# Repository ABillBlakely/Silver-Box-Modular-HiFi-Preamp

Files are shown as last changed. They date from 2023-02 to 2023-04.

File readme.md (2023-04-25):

# Silver Box Modular HiFi Preamp

> __Note: This project is still very early in development. Features, functions, and interfaces are subject to change.__

The Silver Box Modular HiFi Preamp allows a person to choose the exact inputs and outputs that a user wants to have. It is common to need to combine or switch between many different sources which all need to go to a single playback source. For instance a person may have TOSLINK optical from their TV, RCA source from a turntable, and a balanced source from a USB audio interface. With this device, all of those can be accommodated and output to one set of speakers.

The chassis provides the analog signal routing, volume control, switching and indication. It is driven by an ESP32 so that functions can be controlled over WiFi, and eventually with smart home integration.

Peripherals are modular cards that can be slotted in to any of the available channels. Peripherals can be active or passive and can function as inputs, outputs, effects, visualizations, maybe more!

The chassis provides each peripheral with:

- Audio send to summing bus, main bus audio output, and audio out from left-adjacent module.
- Global mute and per peripheral muting.
- +/- 12V, +5V, +3.3V power rails.
- An I2C data interface with interrupt capabilities.
- Automatic identification of common module types with additional configuration possible over I2C.

# Current Status

__April 25 2023 Update:__ The project is currently in the __hardware prototyping__ phase. PCB's have been produced and are being assembled. Very close to beginning testing. A minimum viable product could be functional by end of May 2023.

Design files will be updated here as progress is made.

The current schematics are available in .pdf in the __ecad__ folder:

- [ecad/motherboard.pdf](ecad/motherboard.pdf)
- [ecad/controlboard.pdf](ecad/controlboard.pdf)
- [ecad/peripheral-example-board.pdf](ecad/peripheral-example-board.pdf)
- [ecad/prototype-power-supply.pdf](ecad/prototype-power-supply.pdf)

The current 3D models/assemblies for the project are available in .step format in the __mcad__ folder:

- [mcad/silver-box-modular_assembly.step](mcad/silver-box-modular_assembly.step)
- [mcad/motherboard.step](mcad/motherboard.step)
- [mcad/controlboard.step](mcad/controlboard.step)
- [mcad/peripheral-example-board.step](mcad/peripheral-example-board.step)

The BOM for this project is evolving and changing with the project. The current state of the BOM can be viewed at 

- [Motherboard](https://octopart.com/bom-tool/XiIWqOJY)
- [Peripheral test board](https://octopart.com/bom-tool/2ID8Y56N)
- [Protype power supply](https://octopart.com/bom-tool/b4PDtAU9)

Next steps:

- [ ] Bring docs up to date with current development state.
- [ ] Setup dev environment
- [ ] Document the mcad model and explain key features.
- [ ] Organize and refine the 3d prints that will be required for the prototype.
- [ ] Put together power supply module that will be used for early development.
  	- Board should have breakouts for external lab power option
  	- MCU for development and testing of I2C, power sequencing, power monitoring
  	- Polyfuse or other protection circuit. 
- [x] Create blank/passive modules for prototyping.
- [x] Synchronize/clean the Octopart BOM with the schematic.
- [x] Final review and production of prototype PCB's.

Farther out:

- 4 layer board after hardware features and form is frozen.
- Power supply design following findings learned from prototyping efforts.
- Expand available peripheral designs, active balanced I/O. Headphone amp output, S/PDIF digital input, VU 
- Integrate with MQTT for smart home capabilities. Eventual integration with commercial smart home systems.

# Concept sketches/renders:

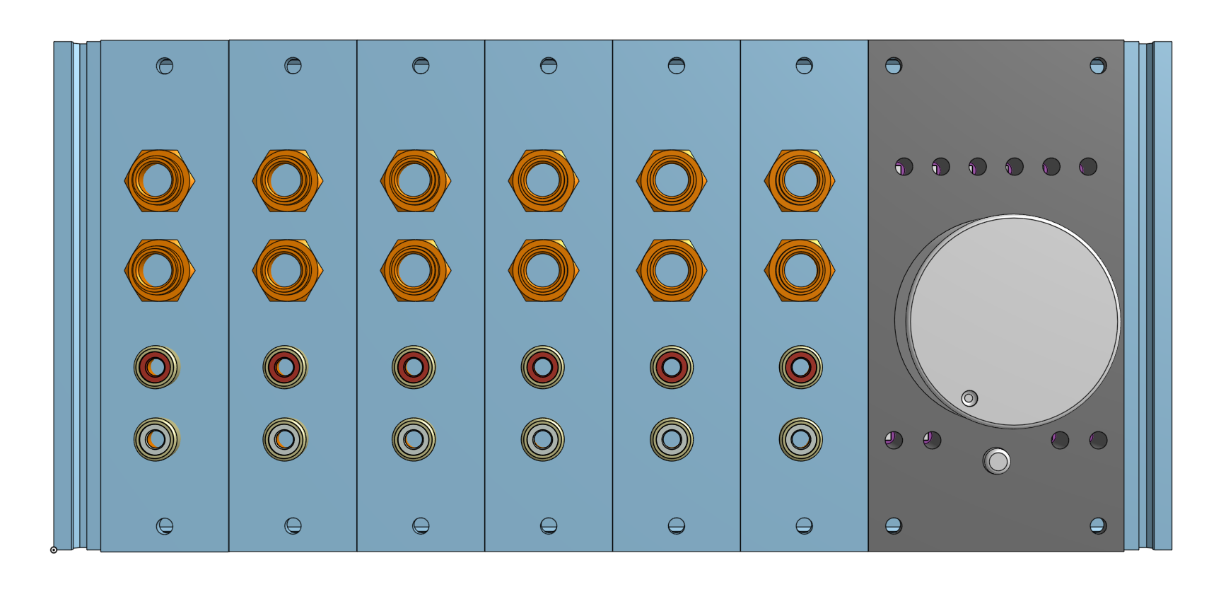
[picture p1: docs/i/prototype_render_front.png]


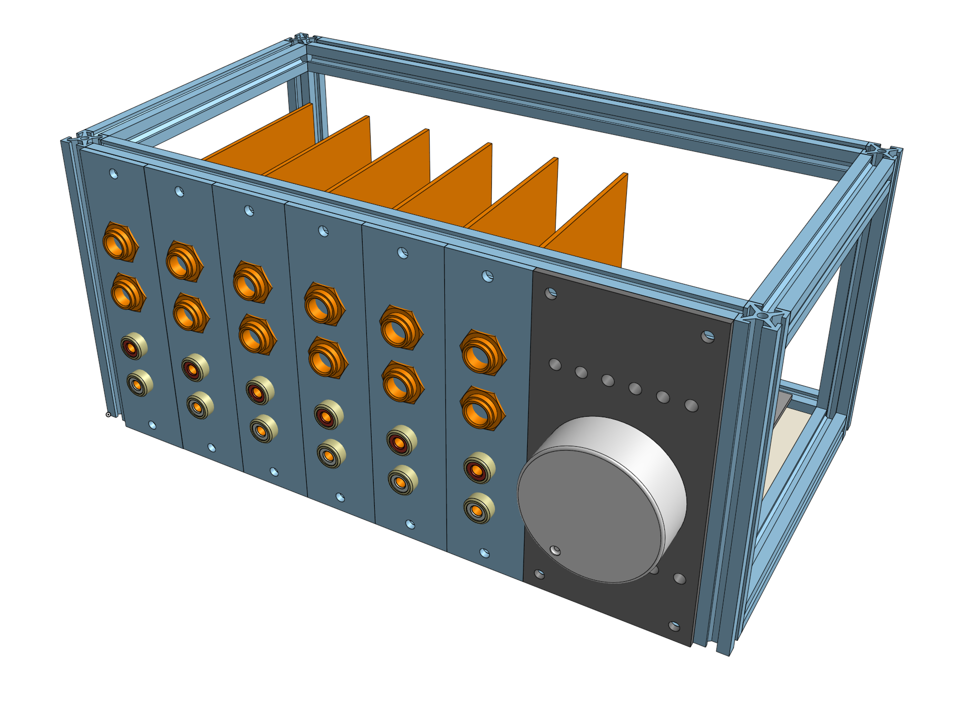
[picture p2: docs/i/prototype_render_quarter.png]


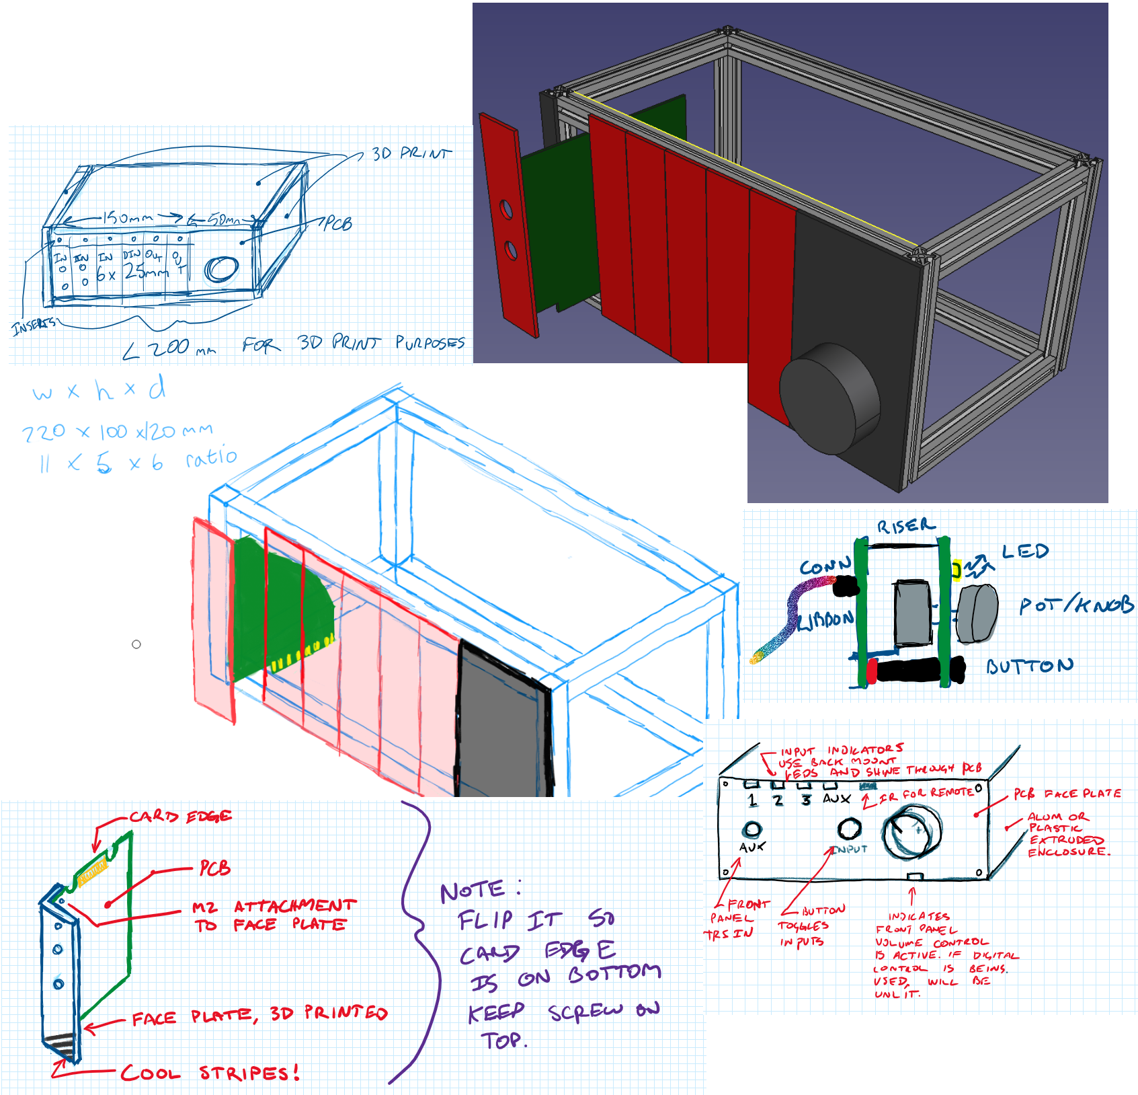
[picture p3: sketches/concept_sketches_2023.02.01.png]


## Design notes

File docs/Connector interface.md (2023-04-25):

# Connector Interface

The Silver Box Modular HiFi Preamp allows a user to swap cards, called peripherals, to facilitate a wide variety of desired input and output combinations. The controller provides the ability to mute individual inputs and provides volume control. The modular interface relies on a 36 pin PCI card edge connector. This connector supplies the peripheral with power, ID's the peripherals function, allows digital communications, and connects the stereo audio to three connection points, described below.

# Audio Send/Receive

Each module has one send and two receives available. Each of these endpoints is a stereo connection.

* __POMI__ Peripheral Out Master In: This sends audio that comes in from an external connector out to the master bus. The controller provides the facility to mute each individual stereo pair sent to POMI. All POMI sends are summed together and sent to the volume control.

* __MOPI__ Master Out, Peripheral In: The signal from the volume control is fed out to every module. Every module sees the same summed signal simultaneously. This means that multiple output peripherals can be installed, but the controller will not be able to select between them. If this behavior is req'd, an advanced output peripheral that includes muting/volume control plus I2C communication should be used.

* __AOPI__ Adjacent Out, Peripheral In: This signal ties to POMI signal of the left-hand adjacent module. It does not go through the buffer, muting, summing, or volume control; it is the raw unbuffered signal from that module. It can be used for a variety of cases such as Input VU meter, Input EQ/Trim, or as a way to bypass the controller board and feed an output module directly. 

# Power

There are 4 power rails available:

* +/-15 V supply is intended to be the analog power supply and should to be used to power any active audio components on the board. 
* 5 V and 3.3 V supplies are intended primarily to power digital devices, These can be used for audio purposes but are generally much noisier. The 5V rail should also be used to pull up the ID pins.

Each power rail has a separate ground return pin on the connector and care should be taken to maintain good routing of these return paths. 

# ID3:0

The ID pins are used to pass basic information about the peripheral back to the controller. This allows for automatic configuration and adaptation of the user interface when a peripheral is swapped. For example, the input button will not select peripherals that do not set the Is_input ID bit. More advanced peripherals can communicate over I2C for additional configuration, but should still communicate as much info as possible over the ID pins. 

> __Note 1: The ID Bit definition is a work in progress and subject to change.__

<!-- I'm not sure if I like "...not output or does not receive...". I might need to include output / not output as well, this could be done without multi state id's by merging USE I2C to the ~INT pin, See Note 2. This decision really comes down to: does the controller need to know what is and is not a simple output.-->

IDN: Low / High

ID0: Sends to POMI (is an input) / No Send (is not an input)

ID1: Receive from AOPI, is output (Ex: controller bypass)/ Receive from AOPI, is not output (ex: Input VU) OR does not receive from AOPI

ID2: Receives from MOPI (is output) / Receive from MOPI but not output (ex: out VU) OR does not receive from MOPI

ID3: Uses I2C / does not use I2C

For instance, the special case of all "high" values could be used in the case of an input VU meter. It receives the unbuffered audio from the adjacent peripheral and visualizes the levels of the input with an led bar graph.

In the future, ID pins may be multi state to allow configuration of more options so to maintain future compatibility ID pins should be strongly pulled up or down. 

# I2C

The controller allows for I2C communication to establish more advanced behavior. As the controller firmware matures, more advanced features will be added to the peripherals. 

The controller I2C bus is multiplexed so each peripheral has a dedicated I2C channel. This prevents any potential conflict in addresses between boards. 

When a peripheral is detected with the "Use I2C" ID pin set, the full address space is scanned to detect all available I2C endpoint addresses. peripherals must set an interrupt in order to send information back to the controller. 

Peripheral/controller communication will function based on a subscribe/notify style of communication. 

# Special Note: Peripheral insertion detection with ~INT and ID3

In the special case where a peripheral is configured with ID3:0 == 1111, it is not possible to determine whether a slot is empty or occupied. For this reason the controller relies on the ~INT pin being pulled low to indicate that a peripheral is inserted. The controller will then scan the ID bits, If  "Use I2C" Bit is also low, the controller will look for a message: a configuration message will indicate a new peripheral and any other message will indicate an unchanged peripheral. If the "Use I2C" bit is high, this will also indicate a new peripheral, and the controller will initialize the new peripheral. 

__In other words, peripherals not using I2C should pull ~INT low, and peripherals with I2C should send an interrupt on power up.__

> __Note 2: ID3 and ~INT could be combined, an ~INT that stays low would indicate no I2C use, and an ~INT the is triggered and then goes high would indicate I2C use. interrupts would need to be under 50ms or something.__

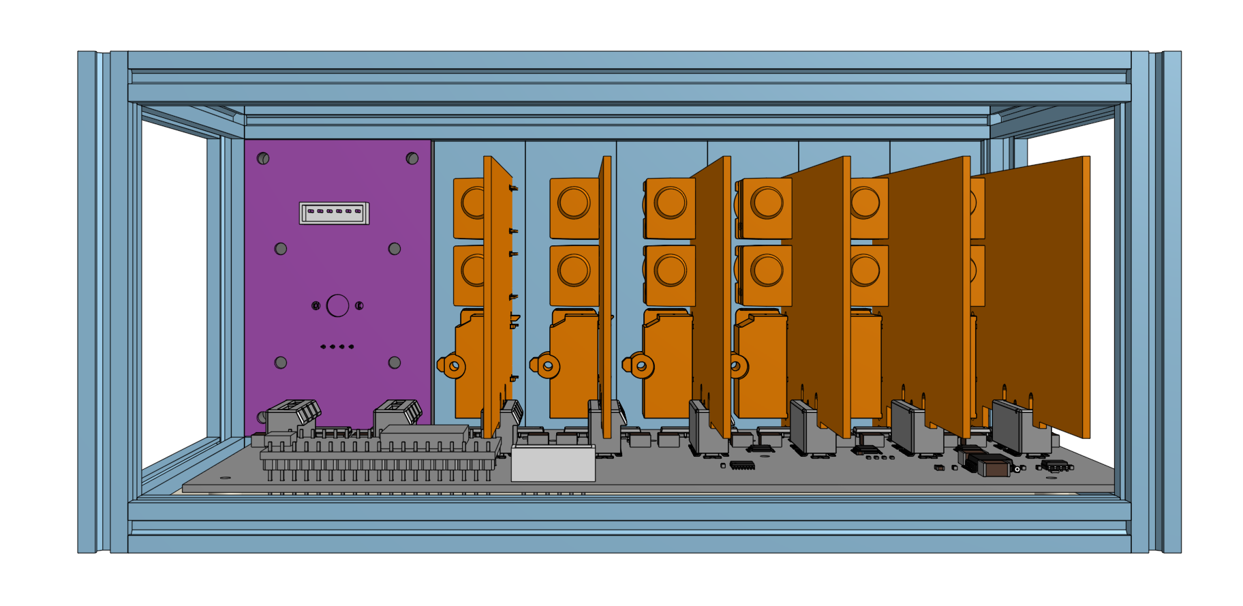
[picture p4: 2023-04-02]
docs/i/prototype_render_back.png

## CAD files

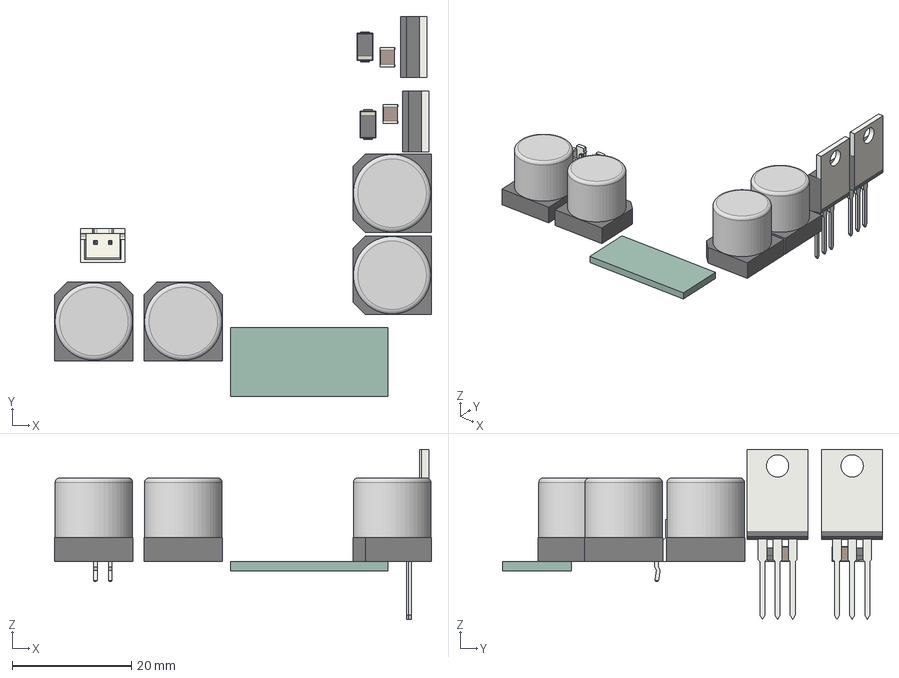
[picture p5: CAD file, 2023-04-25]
mcad/prototype-power-supply.step
63.2 x 63.8 x 28.5 mm
prototype-power-supply PCB

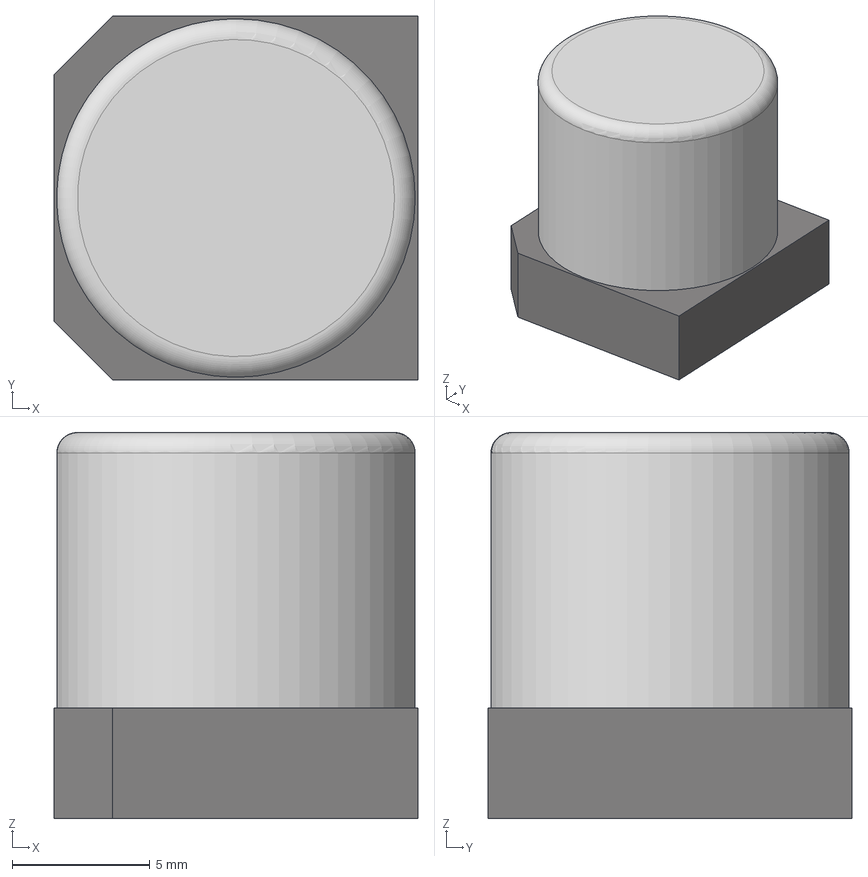
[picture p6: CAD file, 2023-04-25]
mcad/Cap_Elec_12.5x13.5.step
13.2 x 13.2 x 14.0 mm

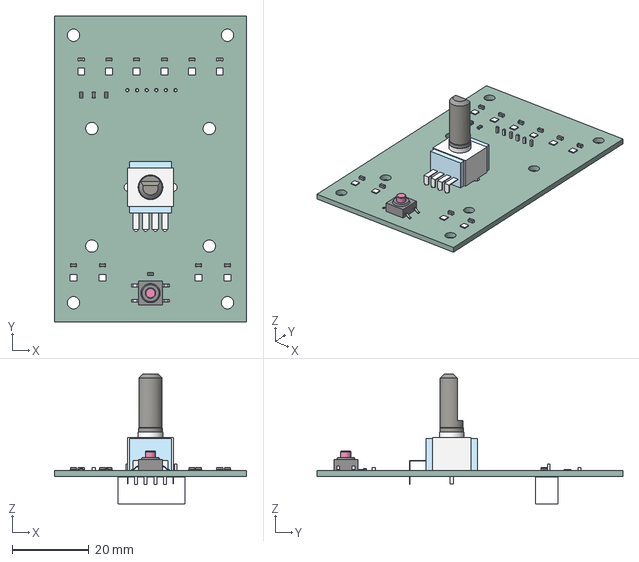
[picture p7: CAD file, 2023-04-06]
mcad/controlboard.step
50.0 x 79.5 x 33.7 mm
PCB

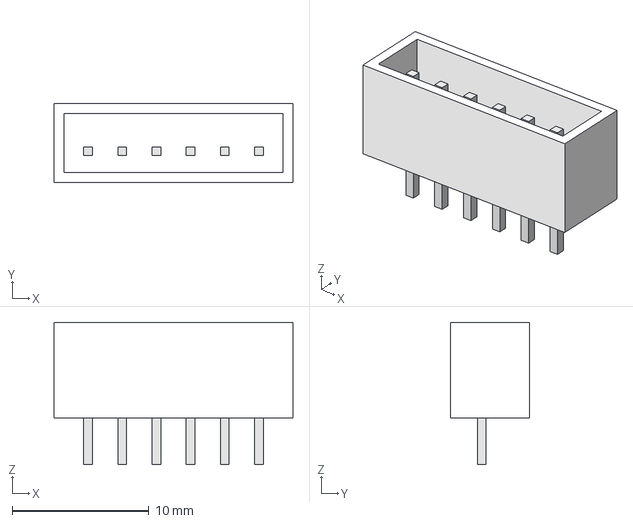
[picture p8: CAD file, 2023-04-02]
mcad/JST-XH-6A.step
17.5 x 5.80 x 10.4 mm

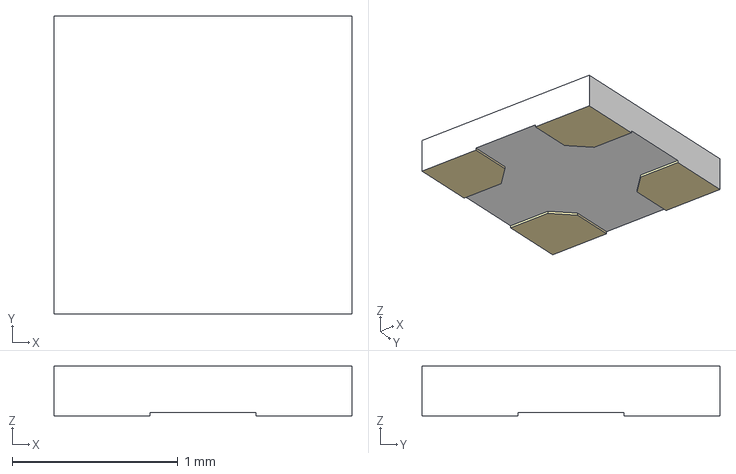
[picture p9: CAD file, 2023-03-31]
mcad/19-C47 RSGHBHC-5V01 2T.step
1.80 x 1.80 x 0.3 mm

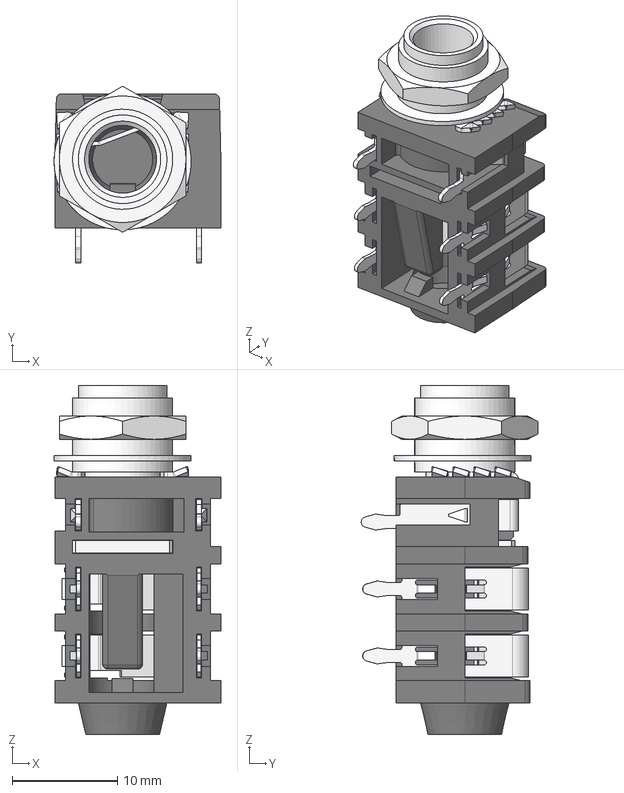
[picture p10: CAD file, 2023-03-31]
mcad/ACJS-MHOM.step
15.8 x 16.7 x 33.1 mm

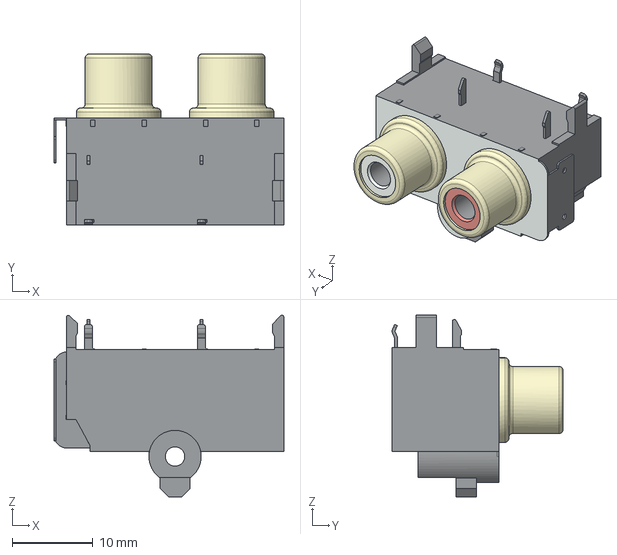
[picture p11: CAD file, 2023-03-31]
mcad/pjras2x1s_series.step
28.5 x 21.2 x 22.5 mm

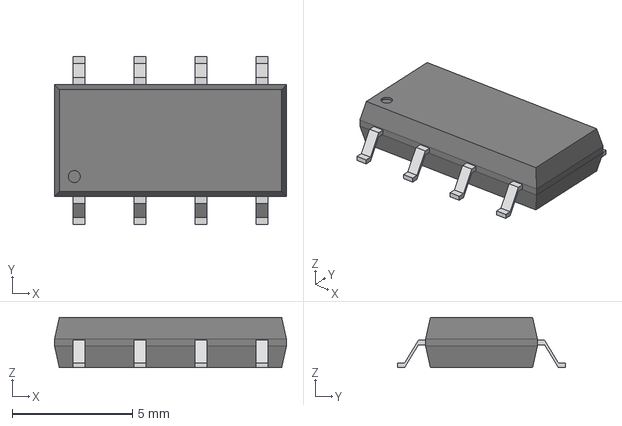
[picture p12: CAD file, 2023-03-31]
mcad/TLP4026G.step
9.65 x 7.00 x 2.10 mm

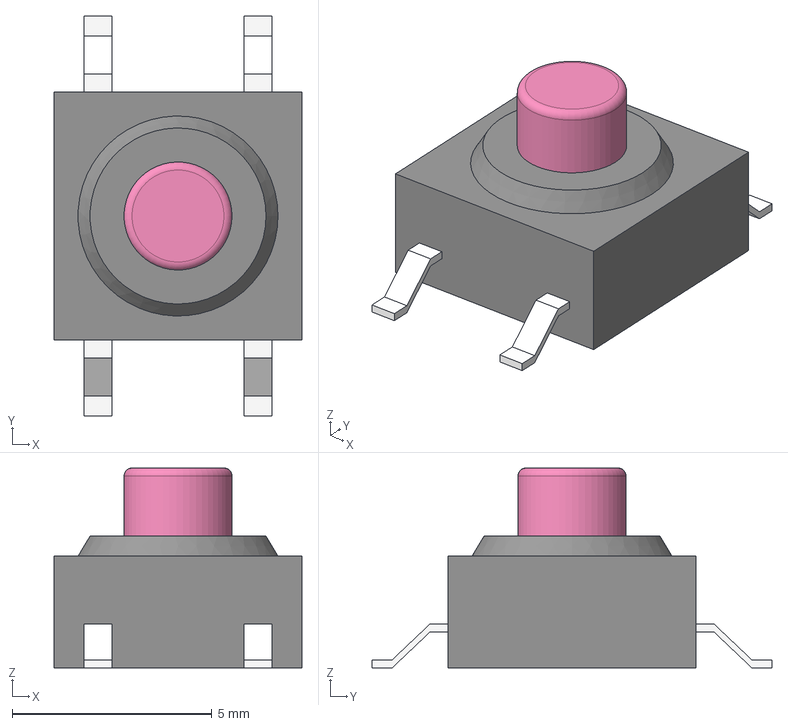
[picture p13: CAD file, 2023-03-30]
mcad/CK switches KSC SLT G.step
6.20 x 10.0 x 5.00 mm

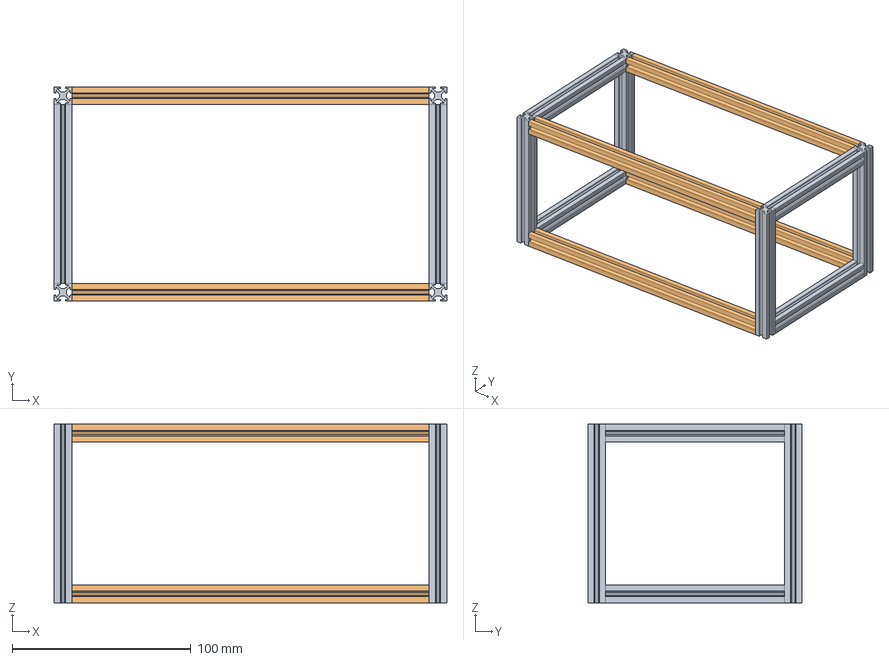
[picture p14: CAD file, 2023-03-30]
mcad/prototype frame.step
220.0 x 120.0 x 100.0 mm
Frame height 2
Frame height 3
Frame height 4
Frame width 1
Frame width 2
Frame width 3
Frame width 4
Frame depth 1
Frame depth 2
Frame depth 3
Frame depth 4
Frame height 1

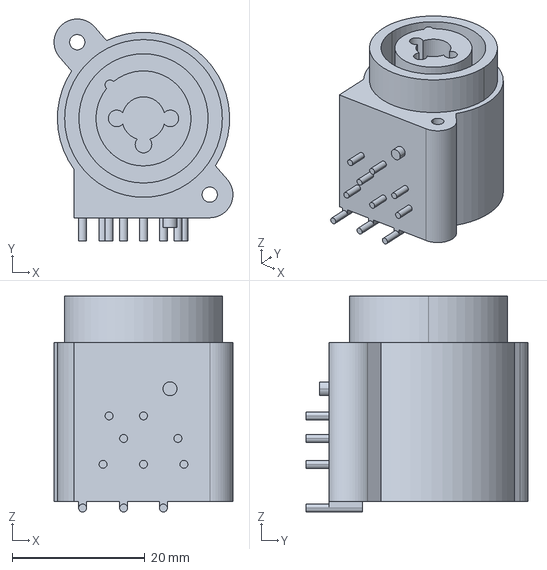
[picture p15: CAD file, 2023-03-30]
mcad/Neutrik ncj9fi-h-0.step
27.0 x 33.5 x 32.6 mm

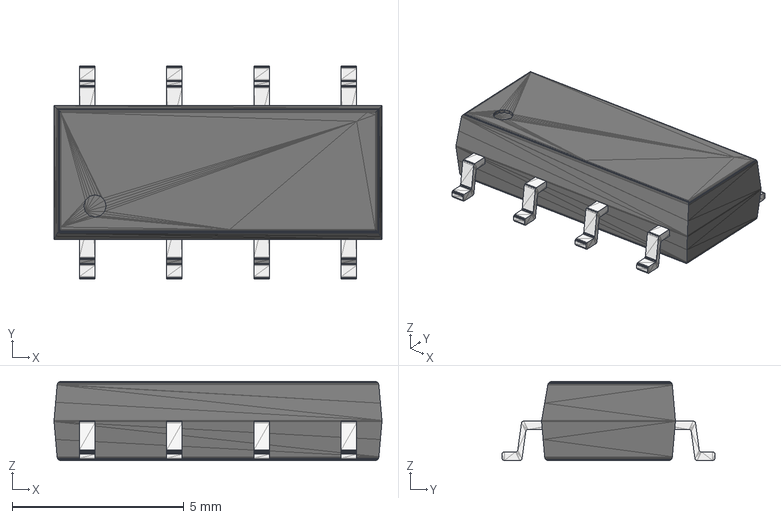
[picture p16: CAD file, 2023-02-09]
mcad/CPC2317N.step
9.55 x 6.20 x 2.30 mm
cpc2317M_body001
cpc2317M_pins001 (Solid)

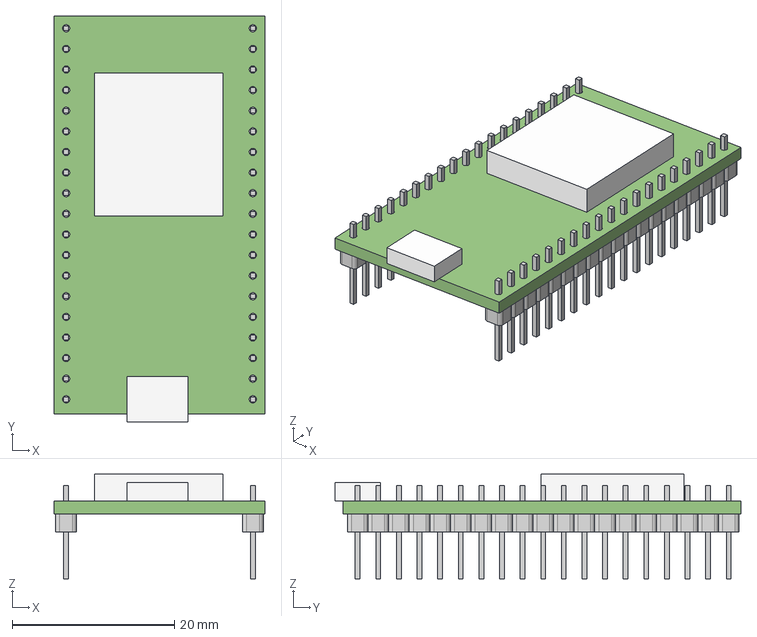
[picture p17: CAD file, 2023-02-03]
mcad/NodeMCU ESP-32S.step
26.0 x 50.0 x 12.9 mm

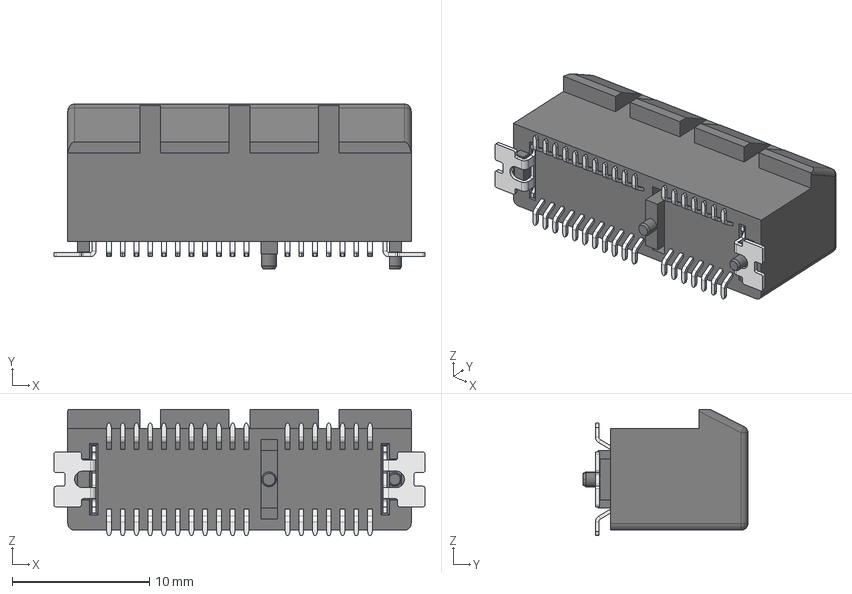
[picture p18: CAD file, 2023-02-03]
mcad/Amphenol 10061913-xx0.stp
27.0 x 12.0 x 9.20 mm
PCI-E_POST_36_5
PRT0032_8_1 x 36
PRT0032_8_2 x 36

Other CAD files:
mcad/Bourns PTV111-4425A.step

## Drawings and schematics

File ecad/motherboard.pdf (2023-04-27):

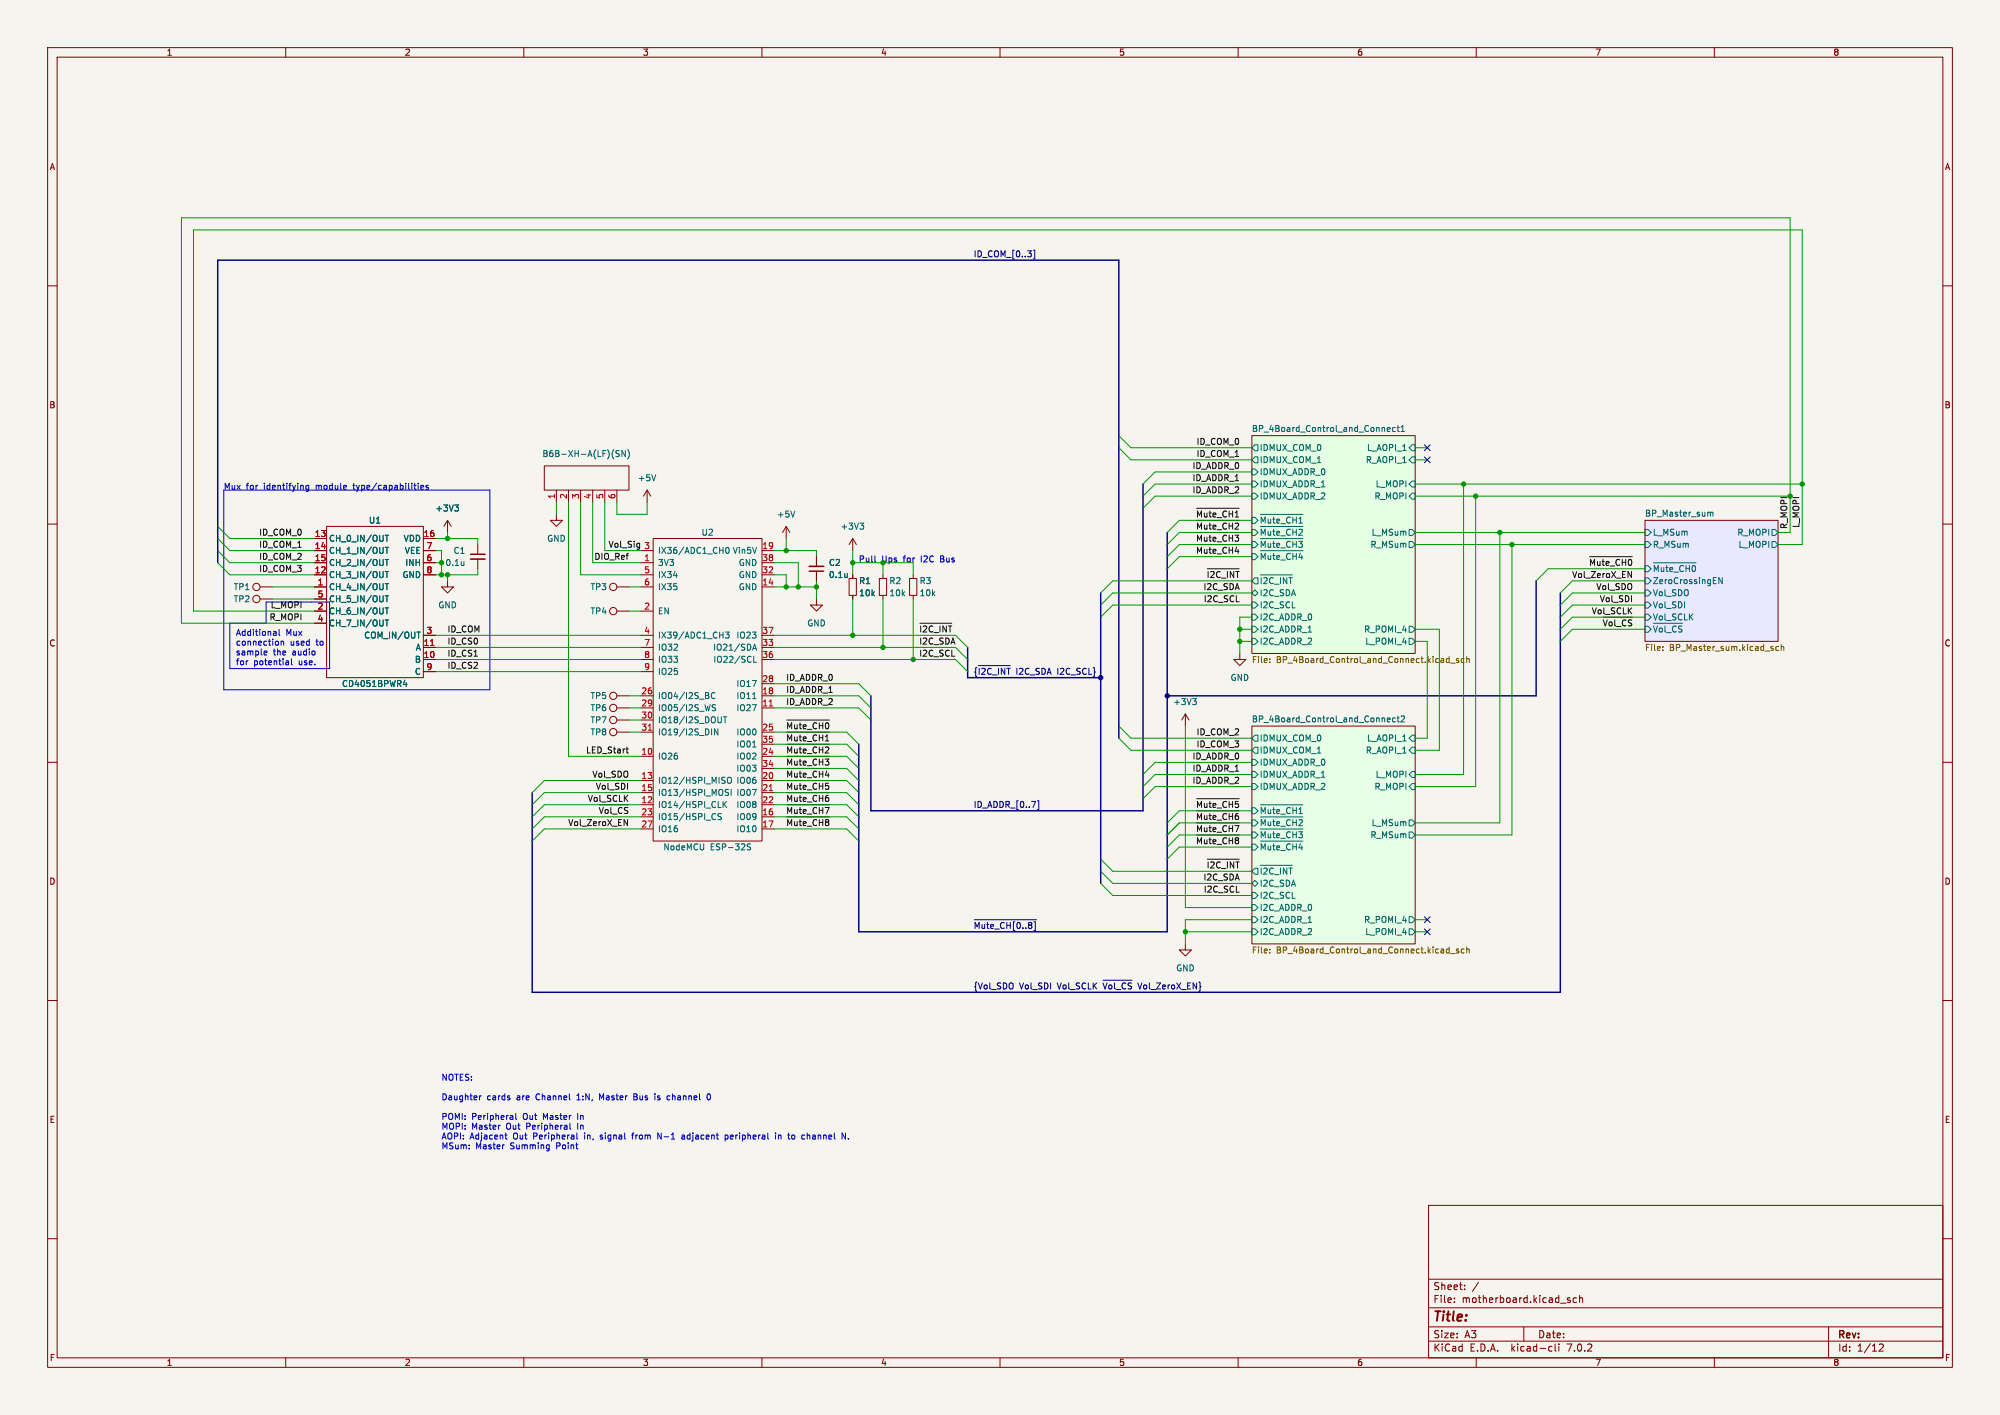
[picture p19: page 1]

Id: 1/12 Title: File: motherboard.kicad_sch Sheet: /

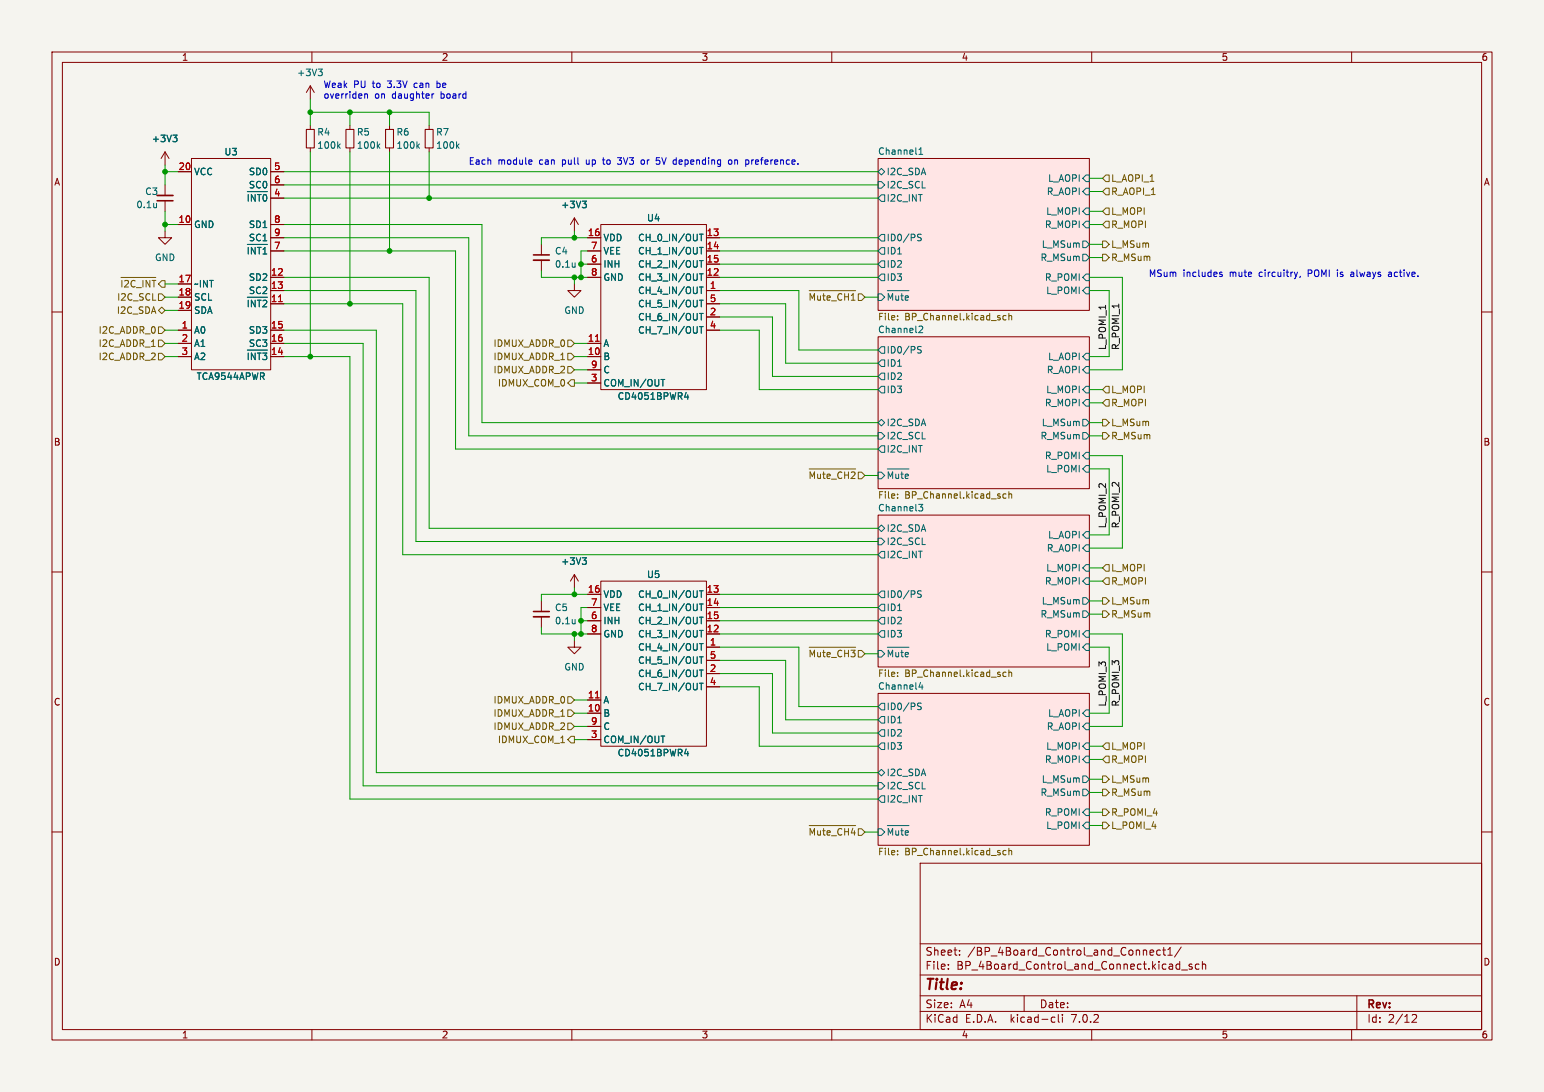
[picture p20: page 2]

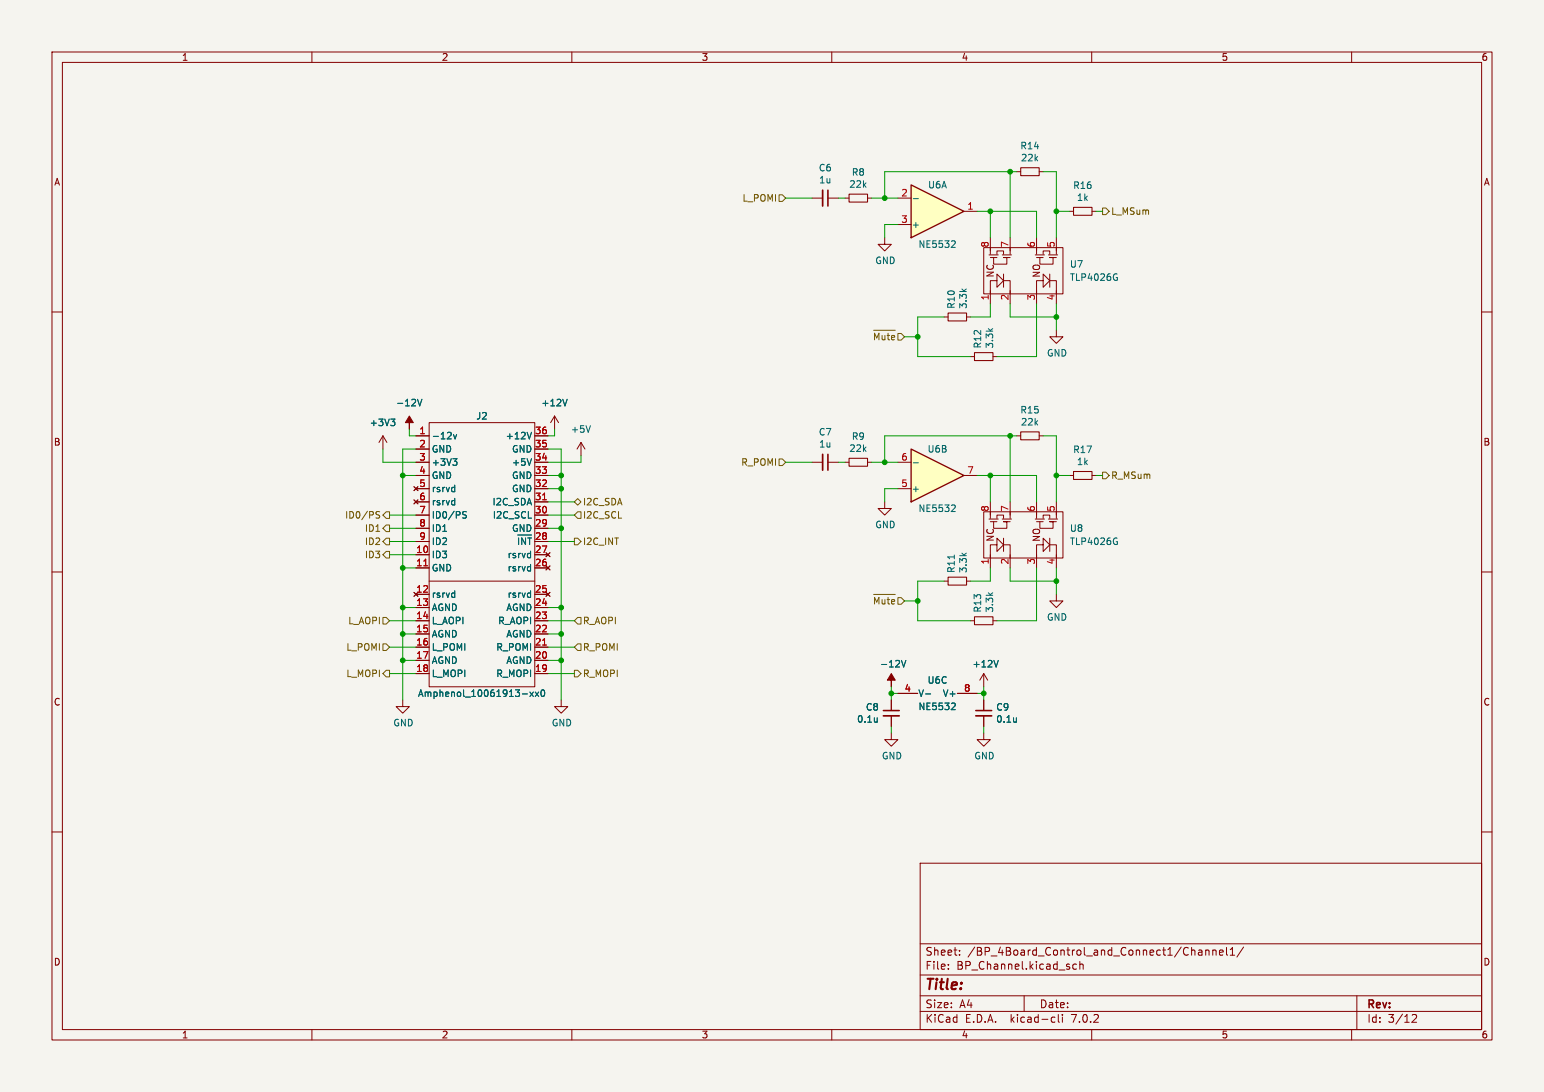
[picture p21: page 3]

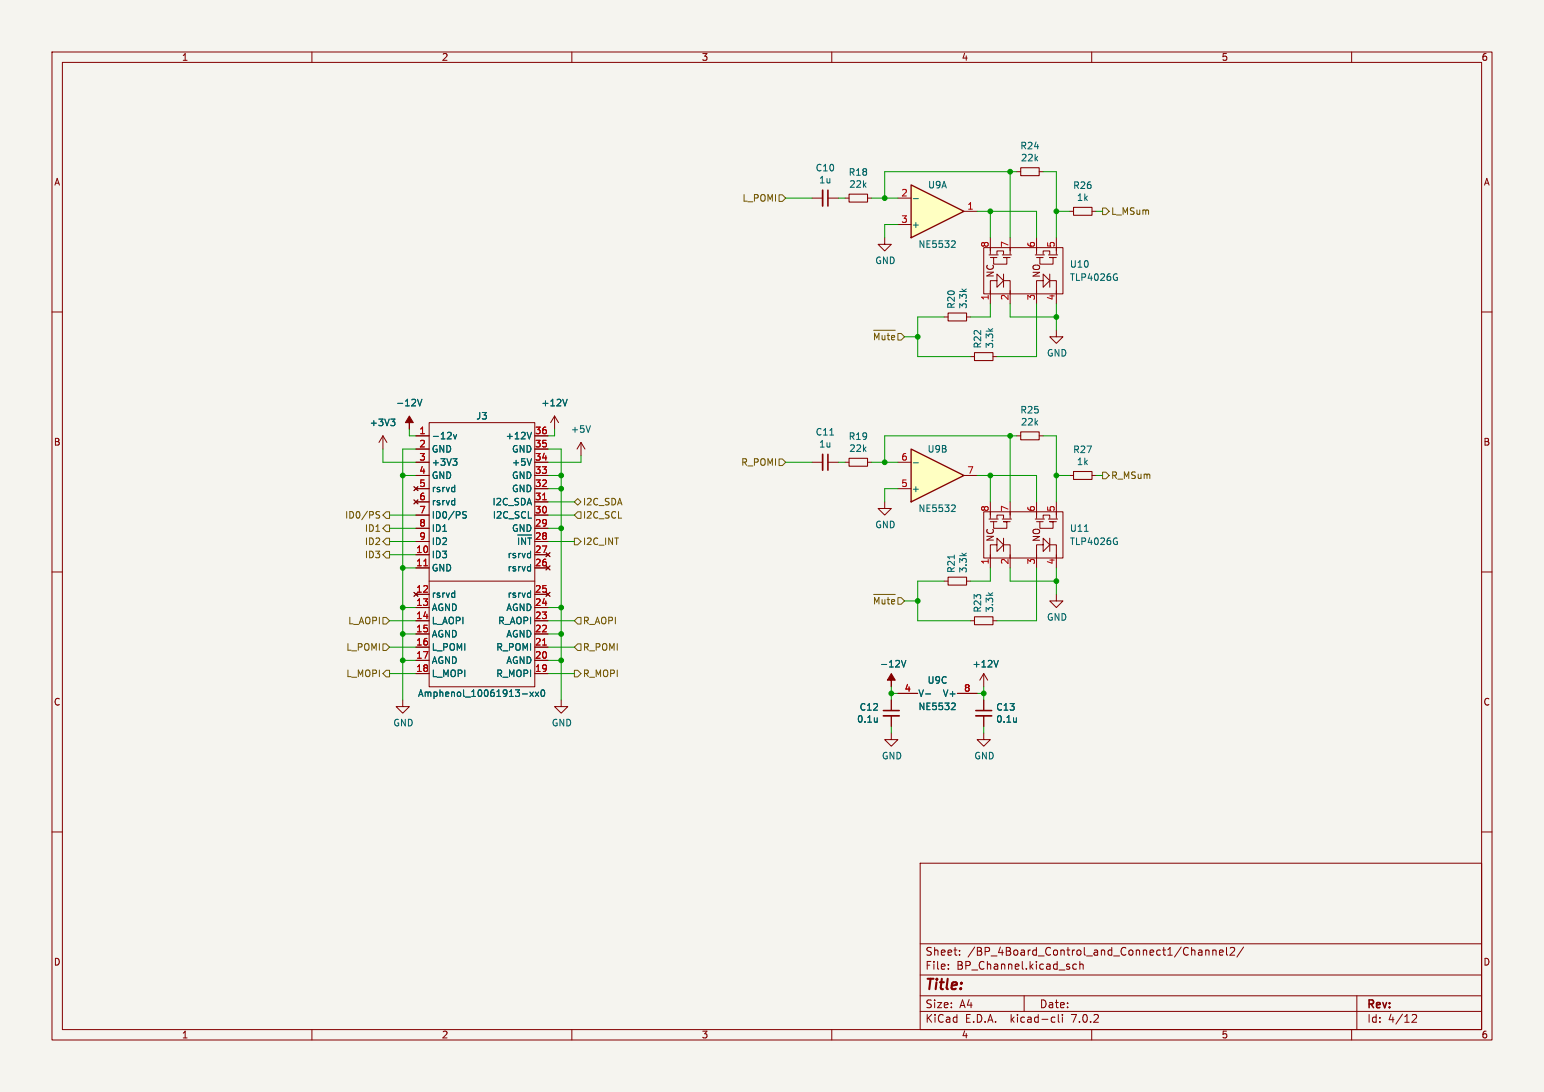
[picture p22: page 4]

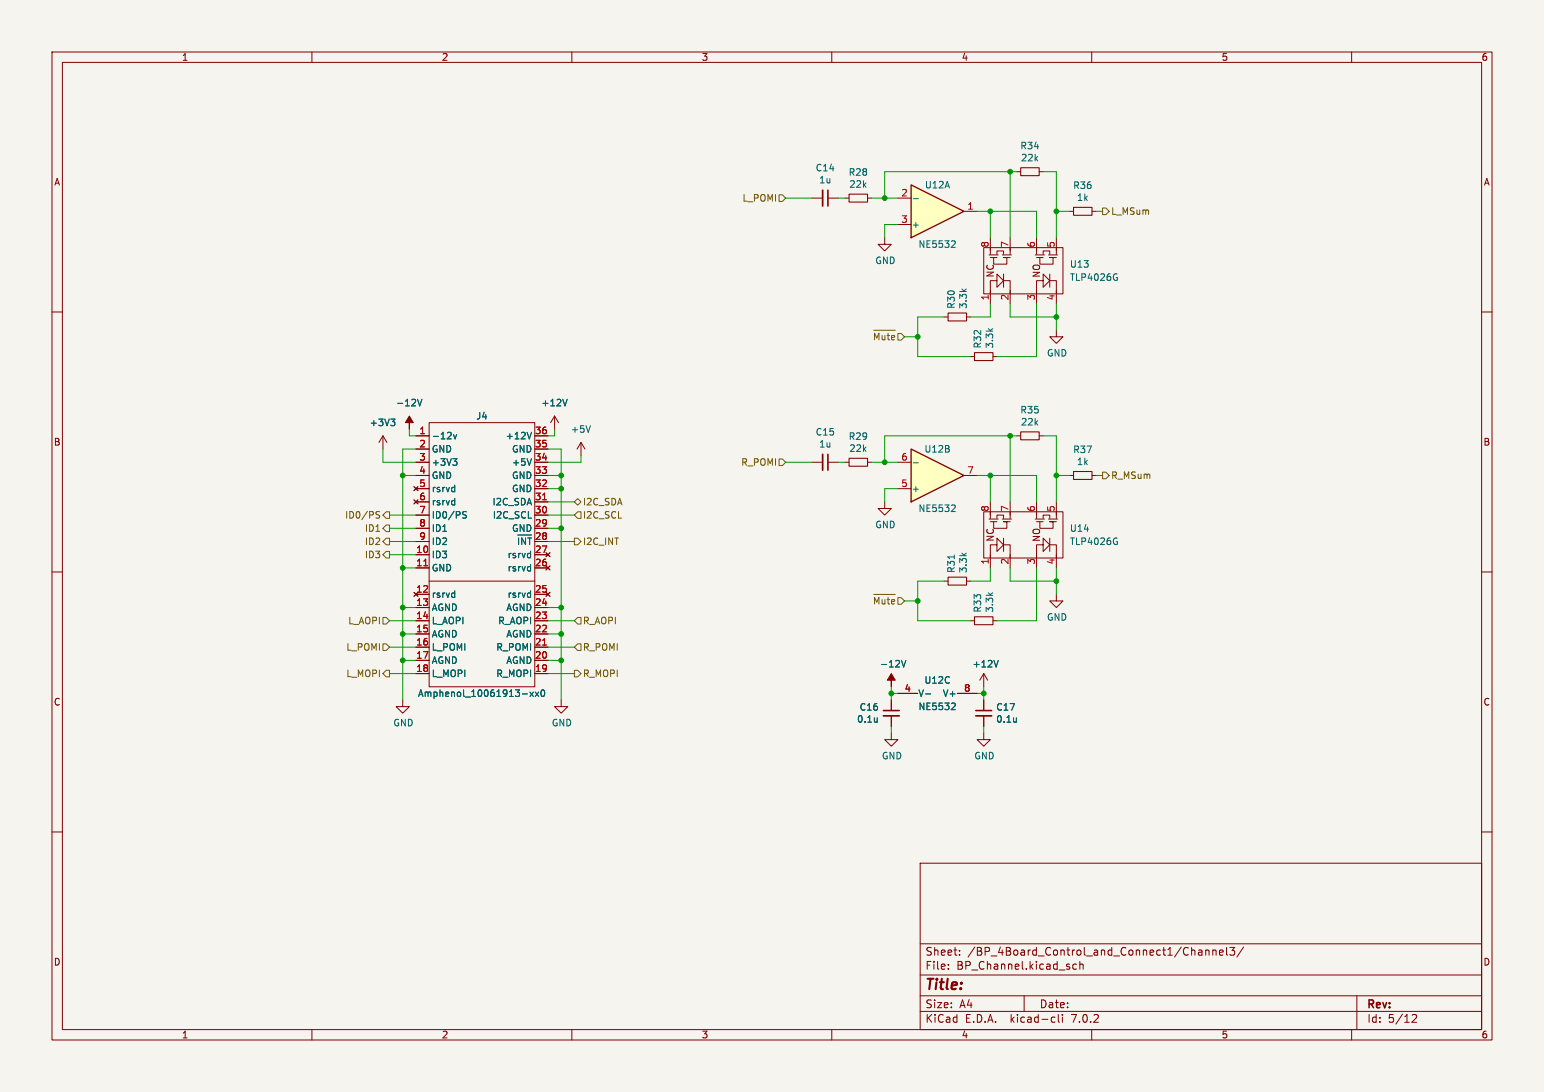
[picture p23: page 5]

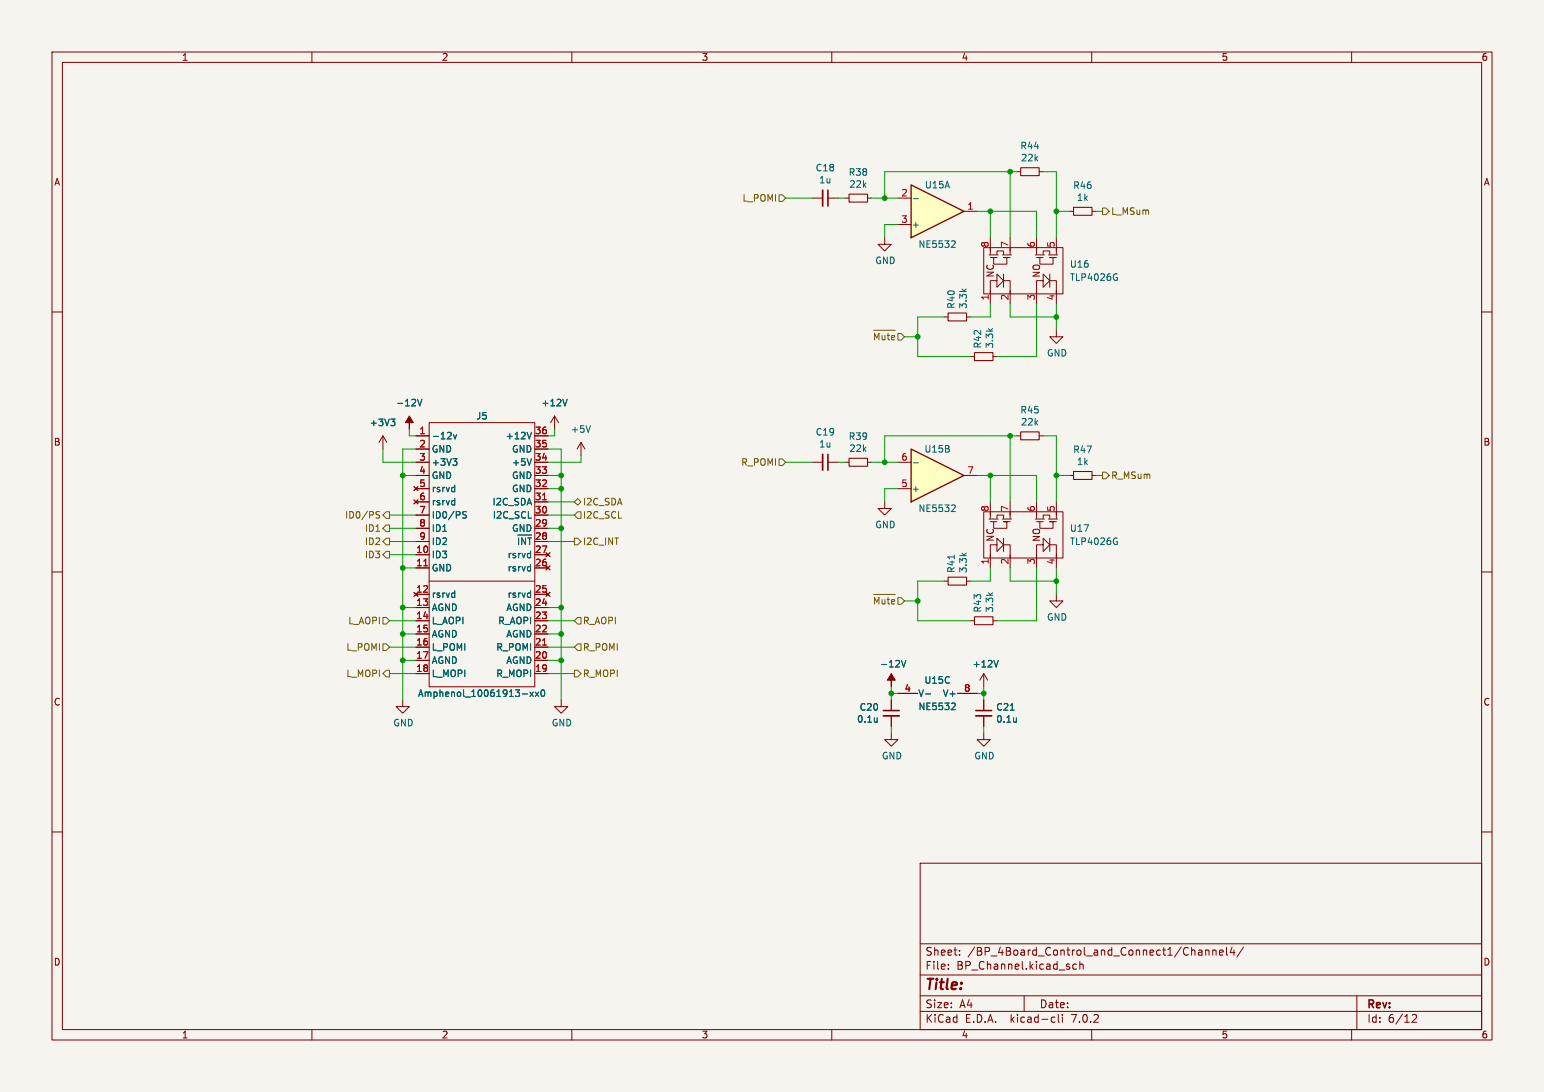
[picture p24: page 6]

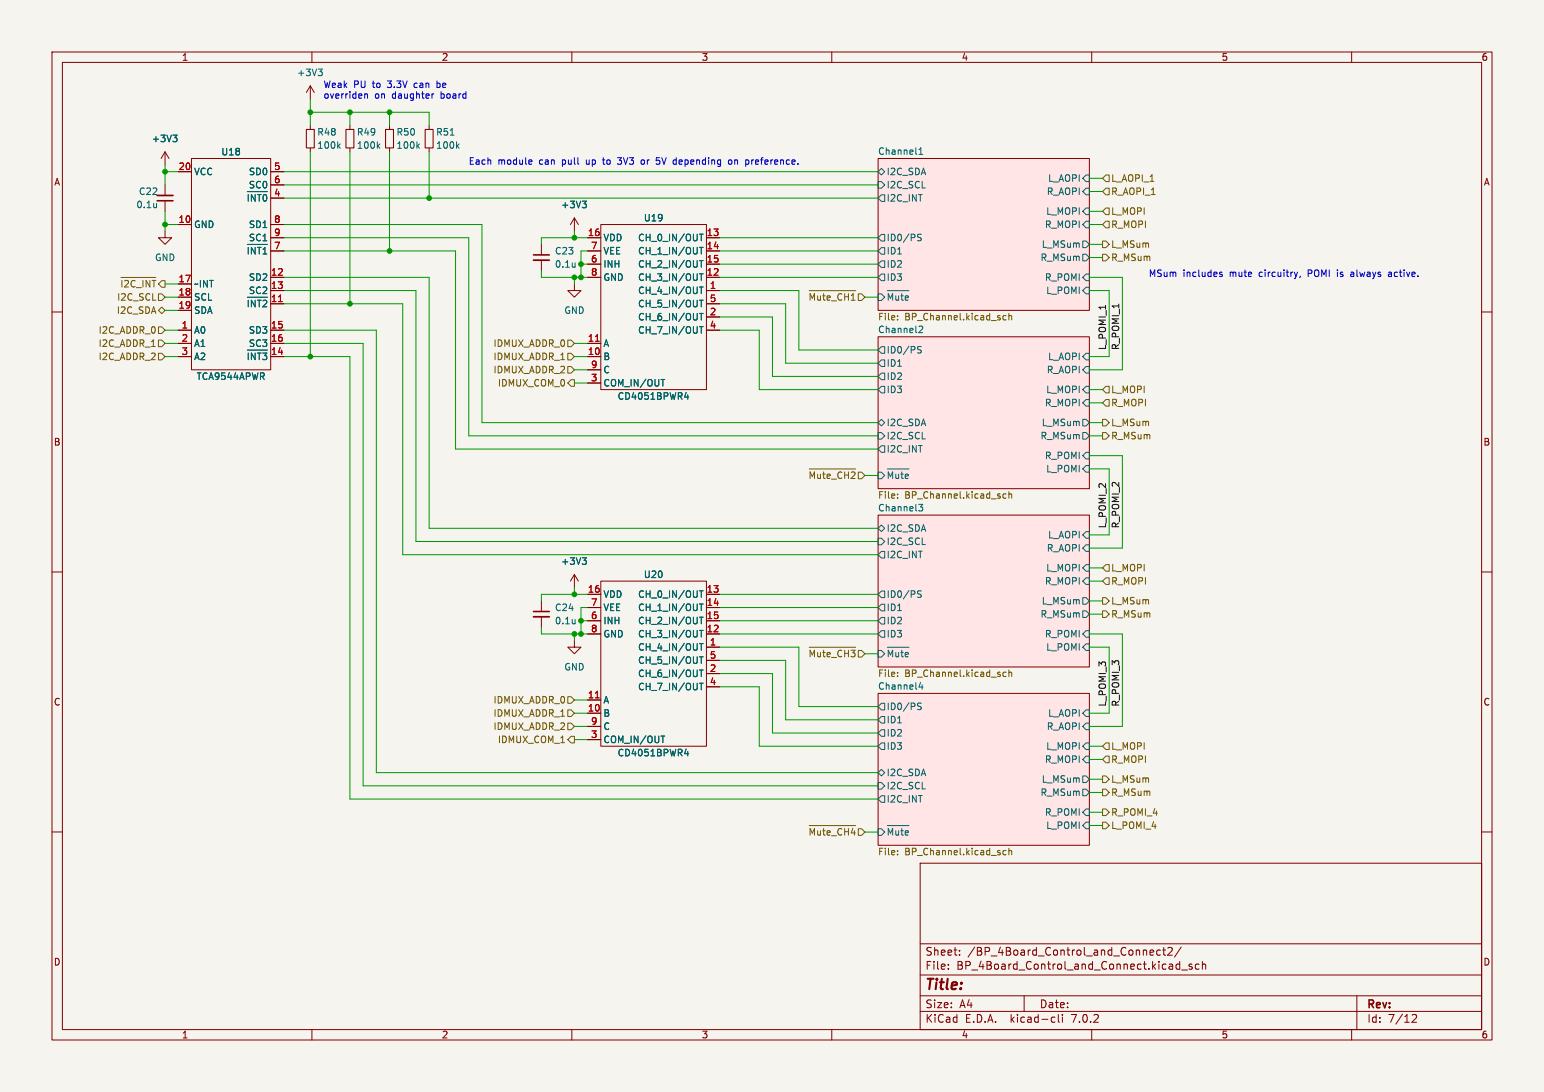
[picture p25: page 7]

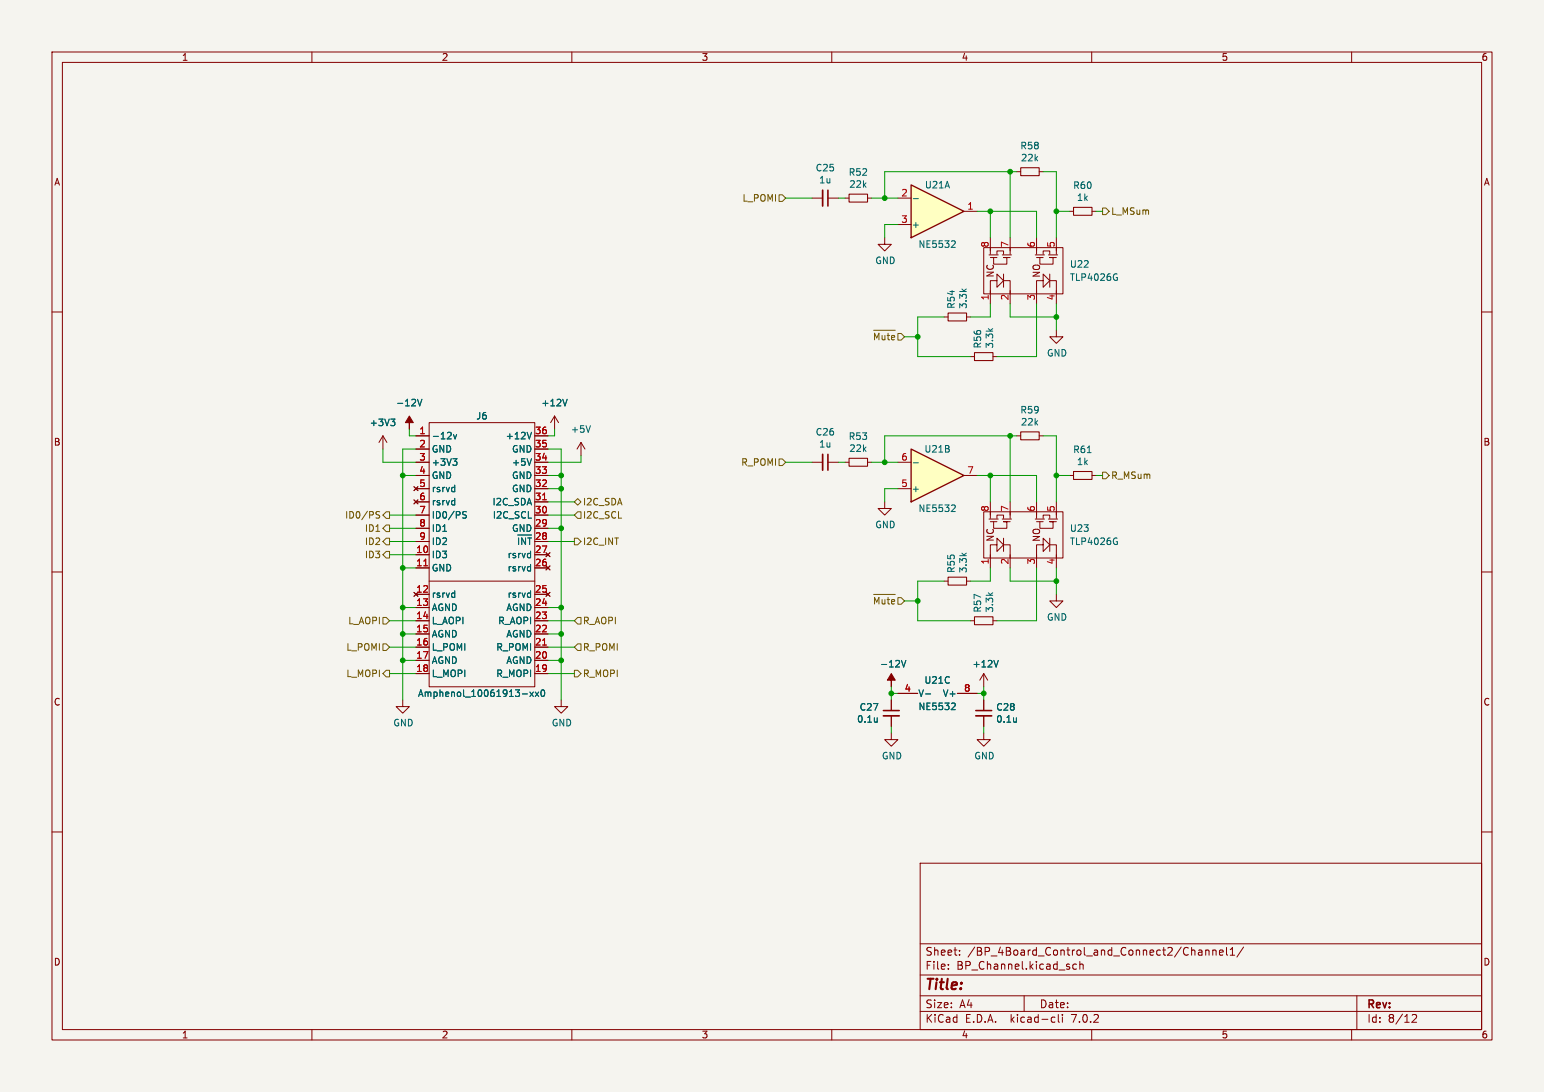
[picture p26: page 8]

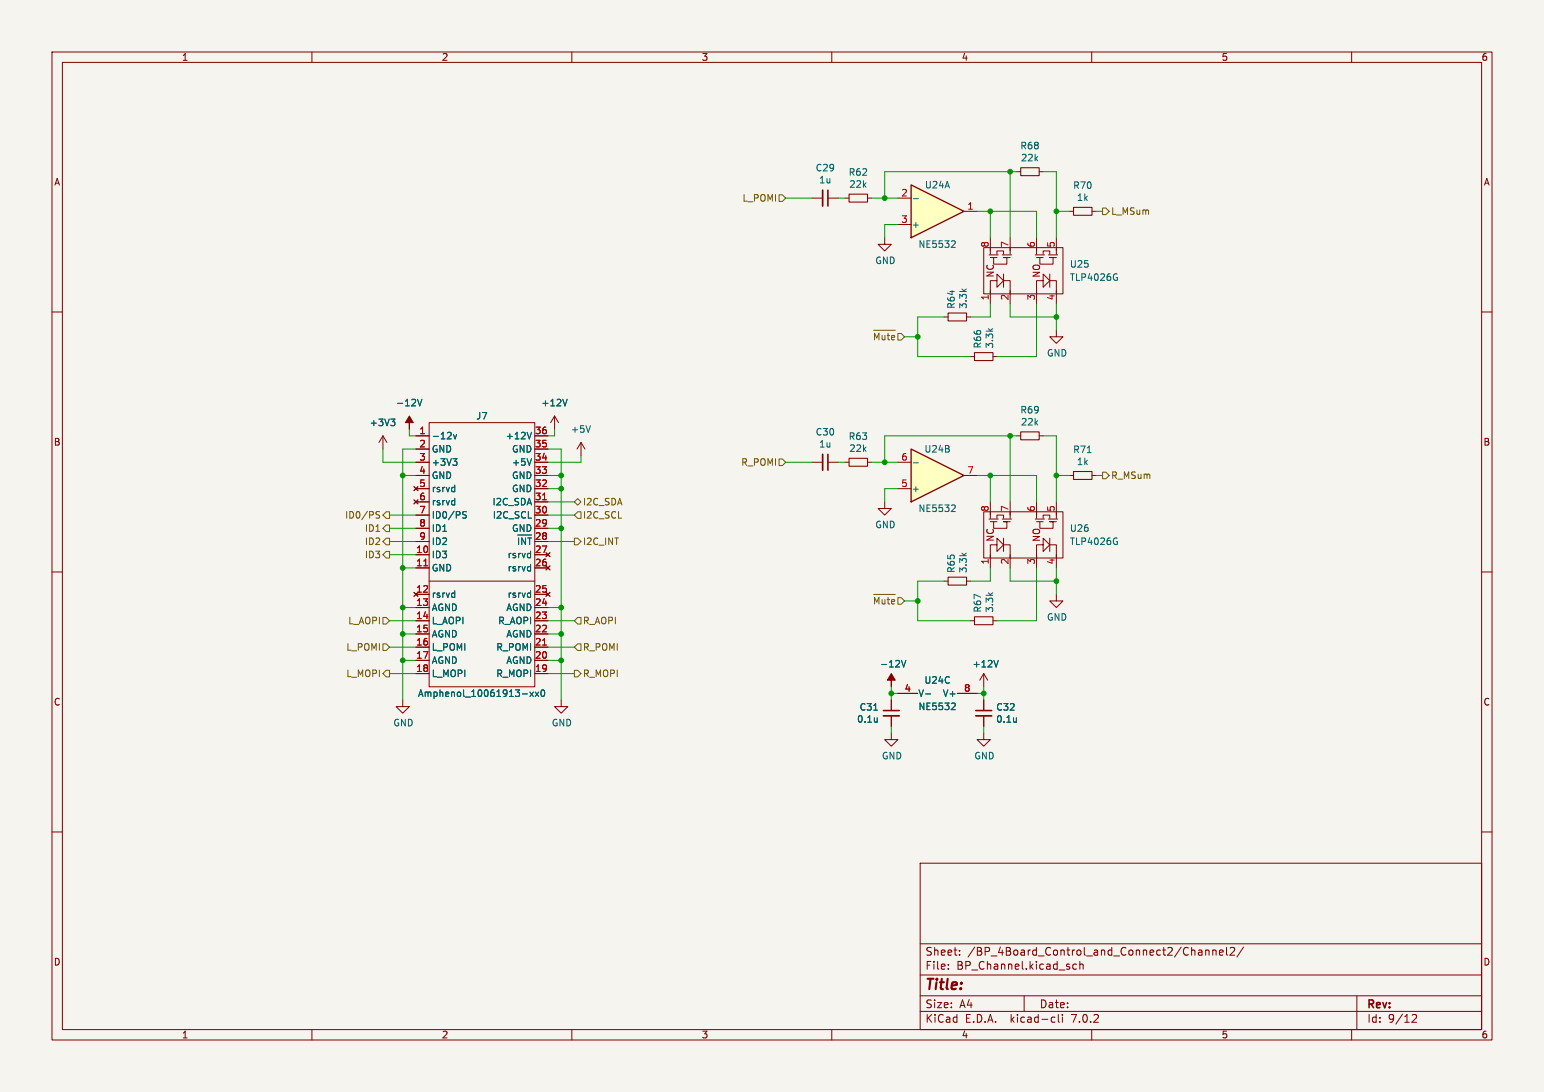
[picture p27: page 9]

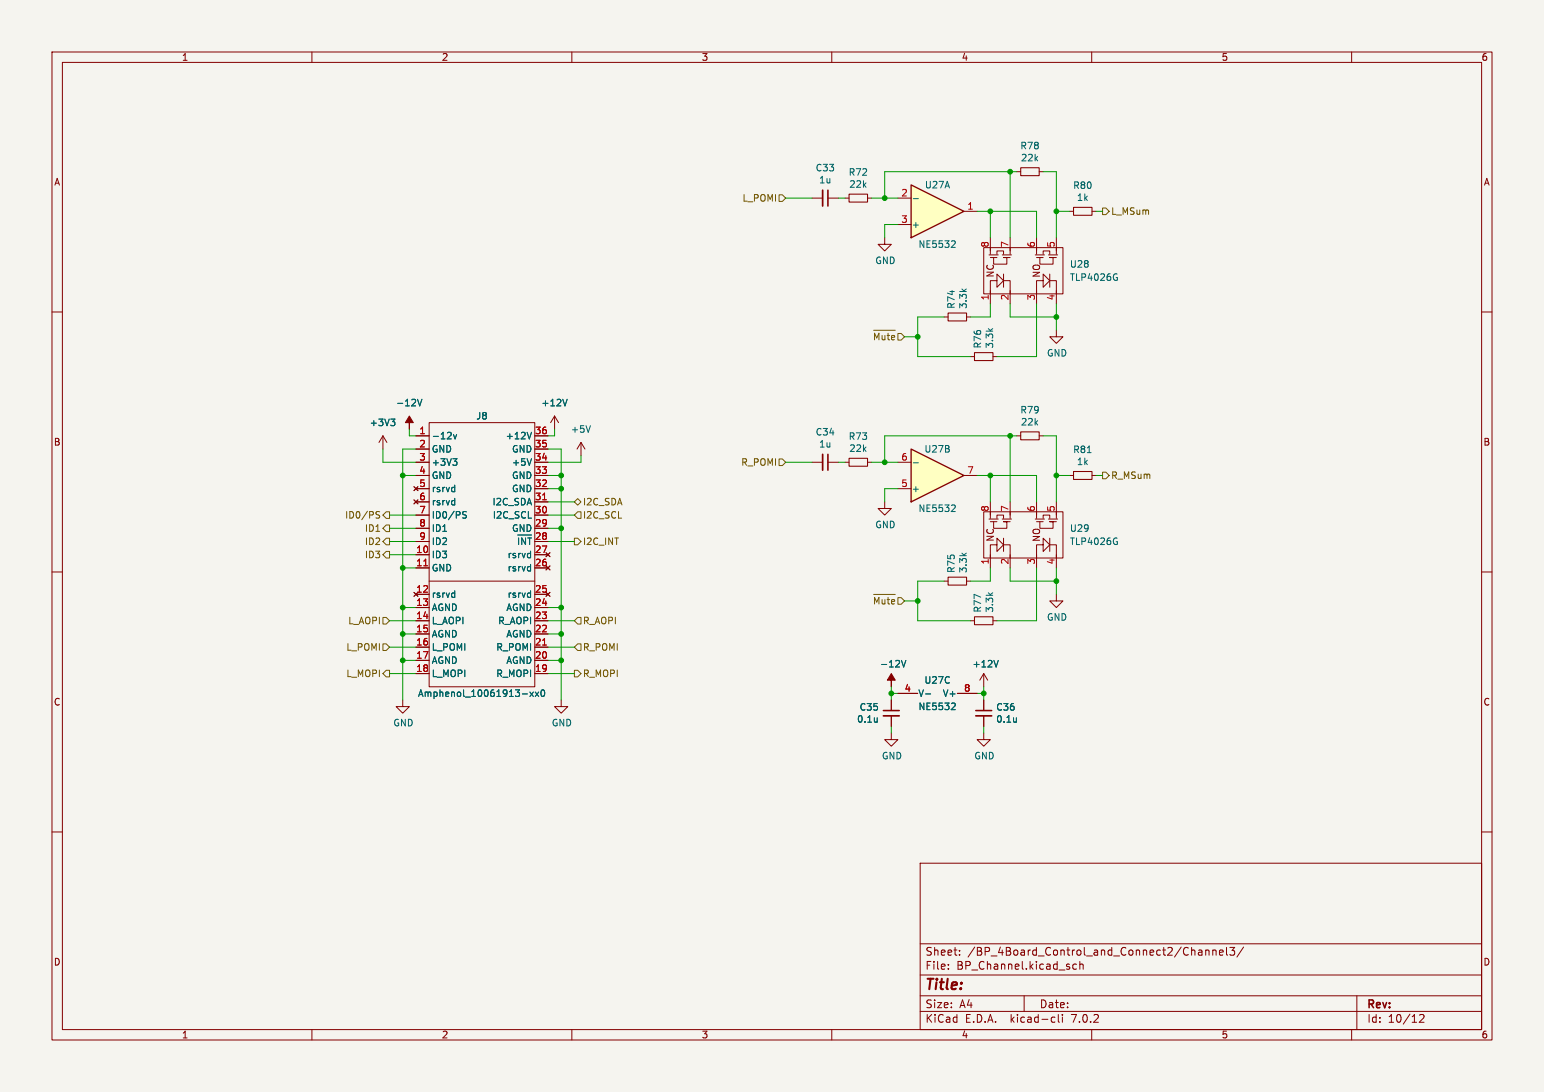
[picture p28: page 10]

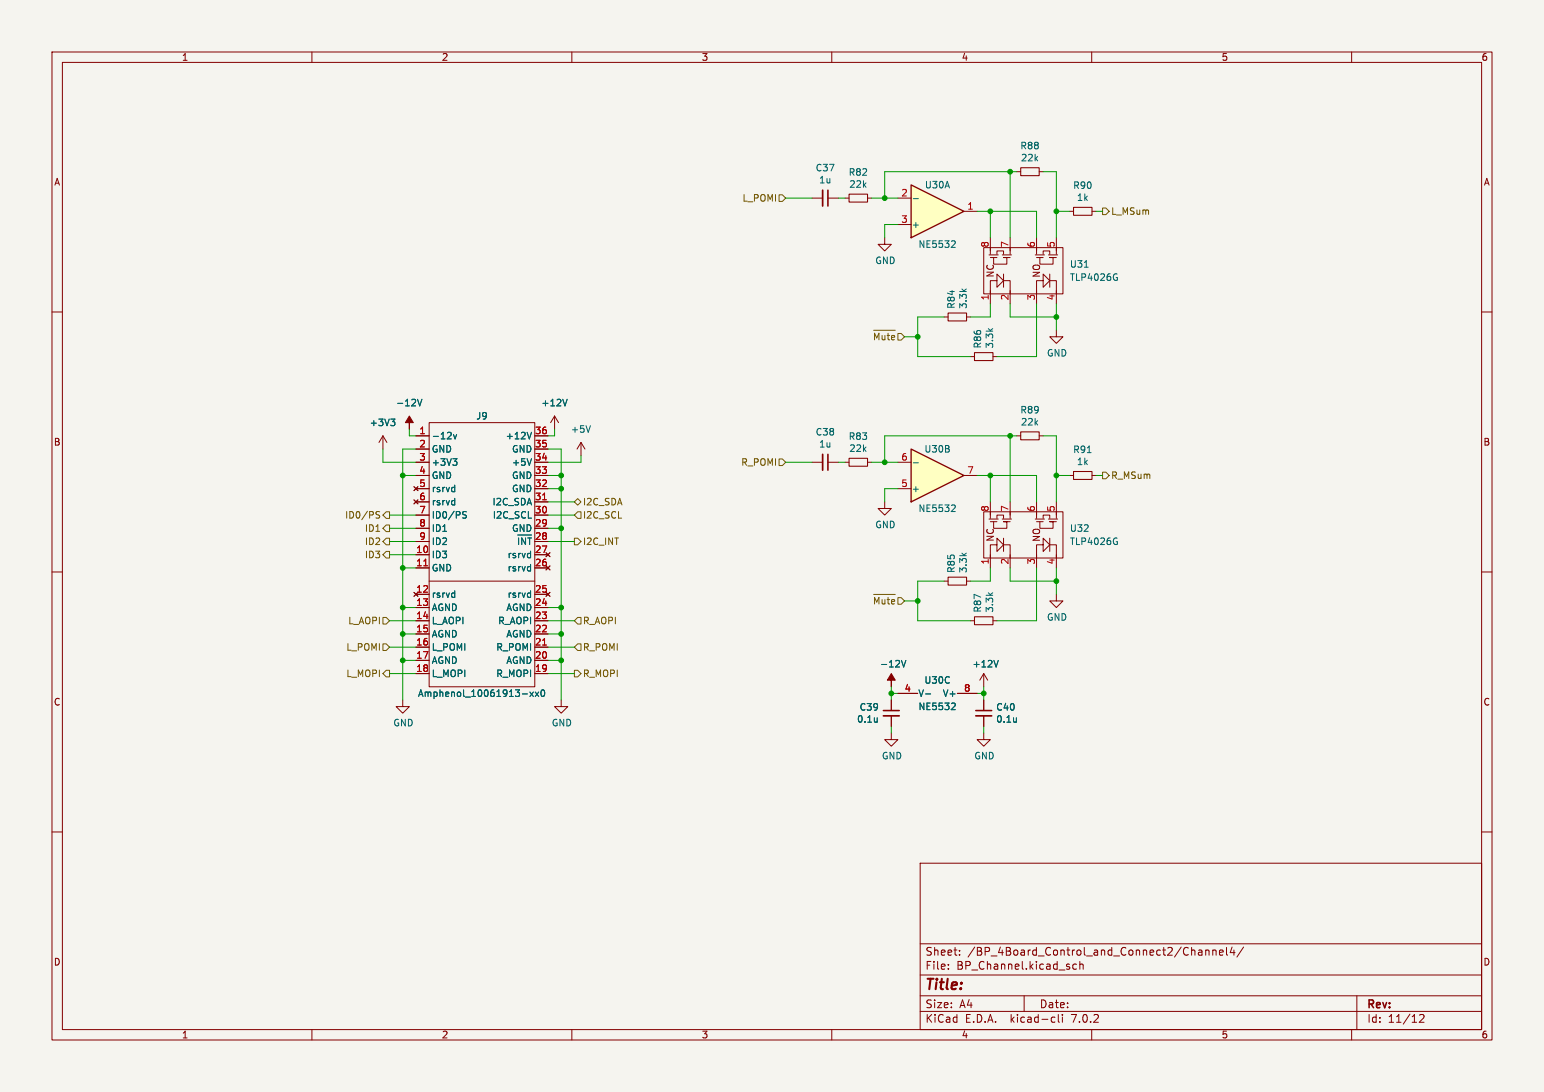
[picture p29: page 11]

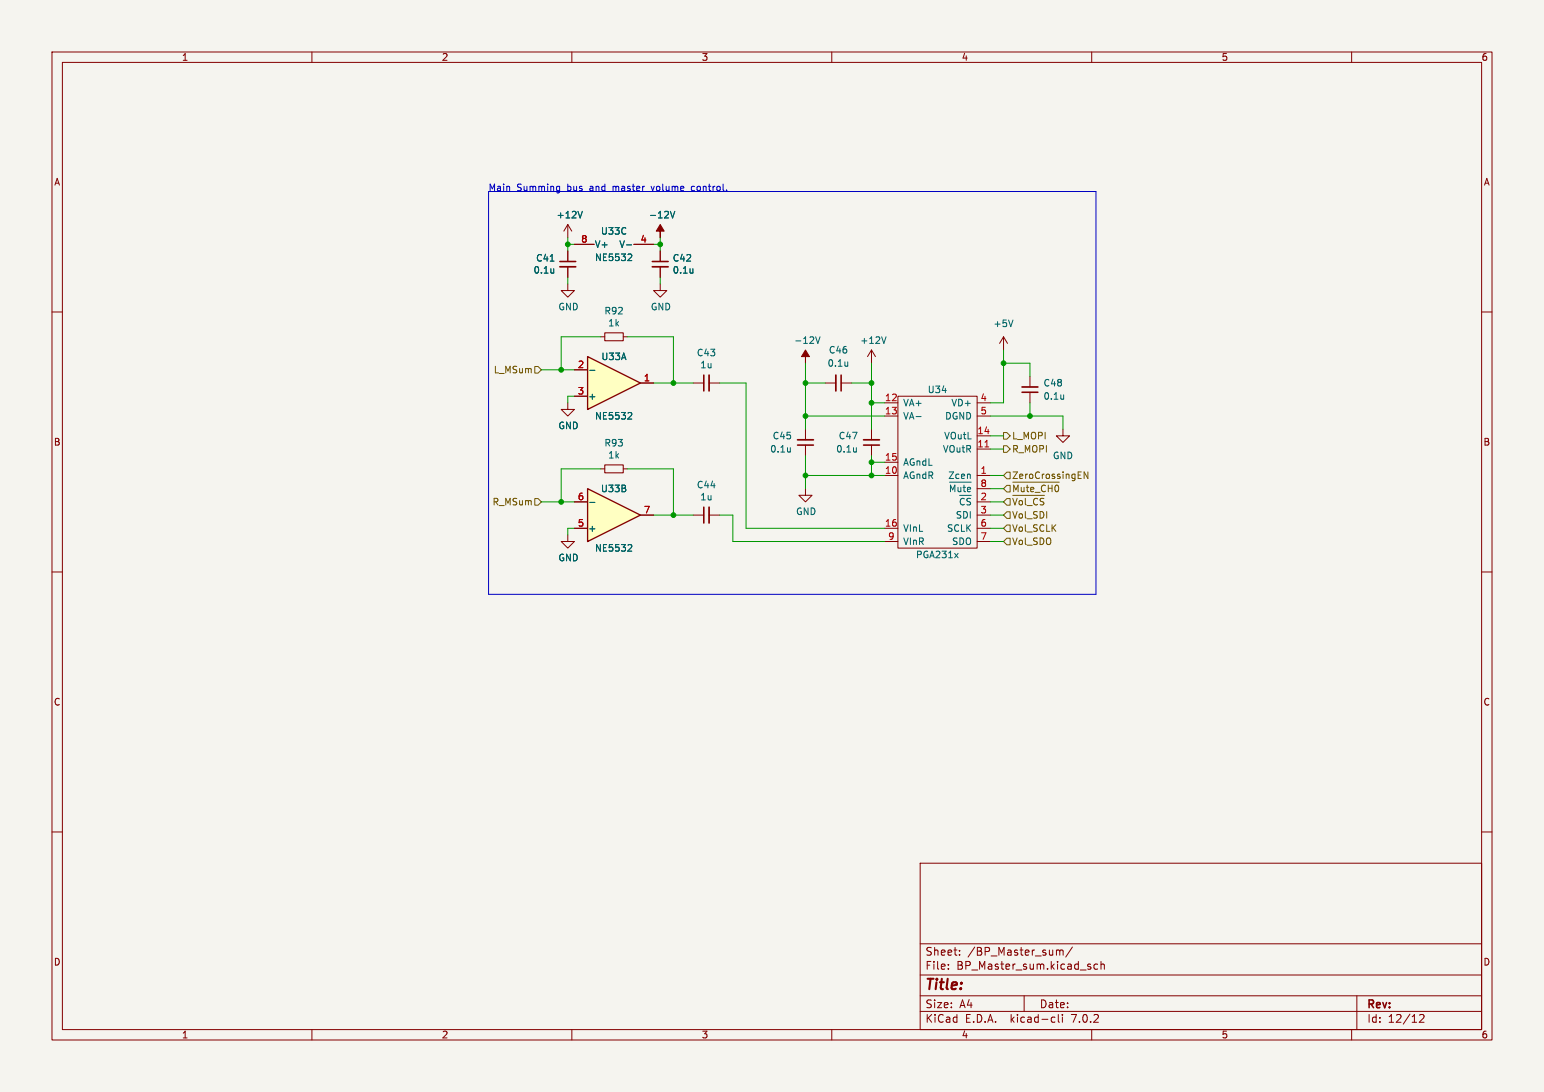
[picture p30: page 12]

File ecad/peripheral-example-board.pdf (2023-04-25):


L_MOPI Could be dip switch or solder bridges

Stereo TRS IO Pair: 101X0011

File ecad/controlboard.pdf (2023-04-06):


Id: 1/1 Title: File: controlboard.kicad_sch Sheet: /


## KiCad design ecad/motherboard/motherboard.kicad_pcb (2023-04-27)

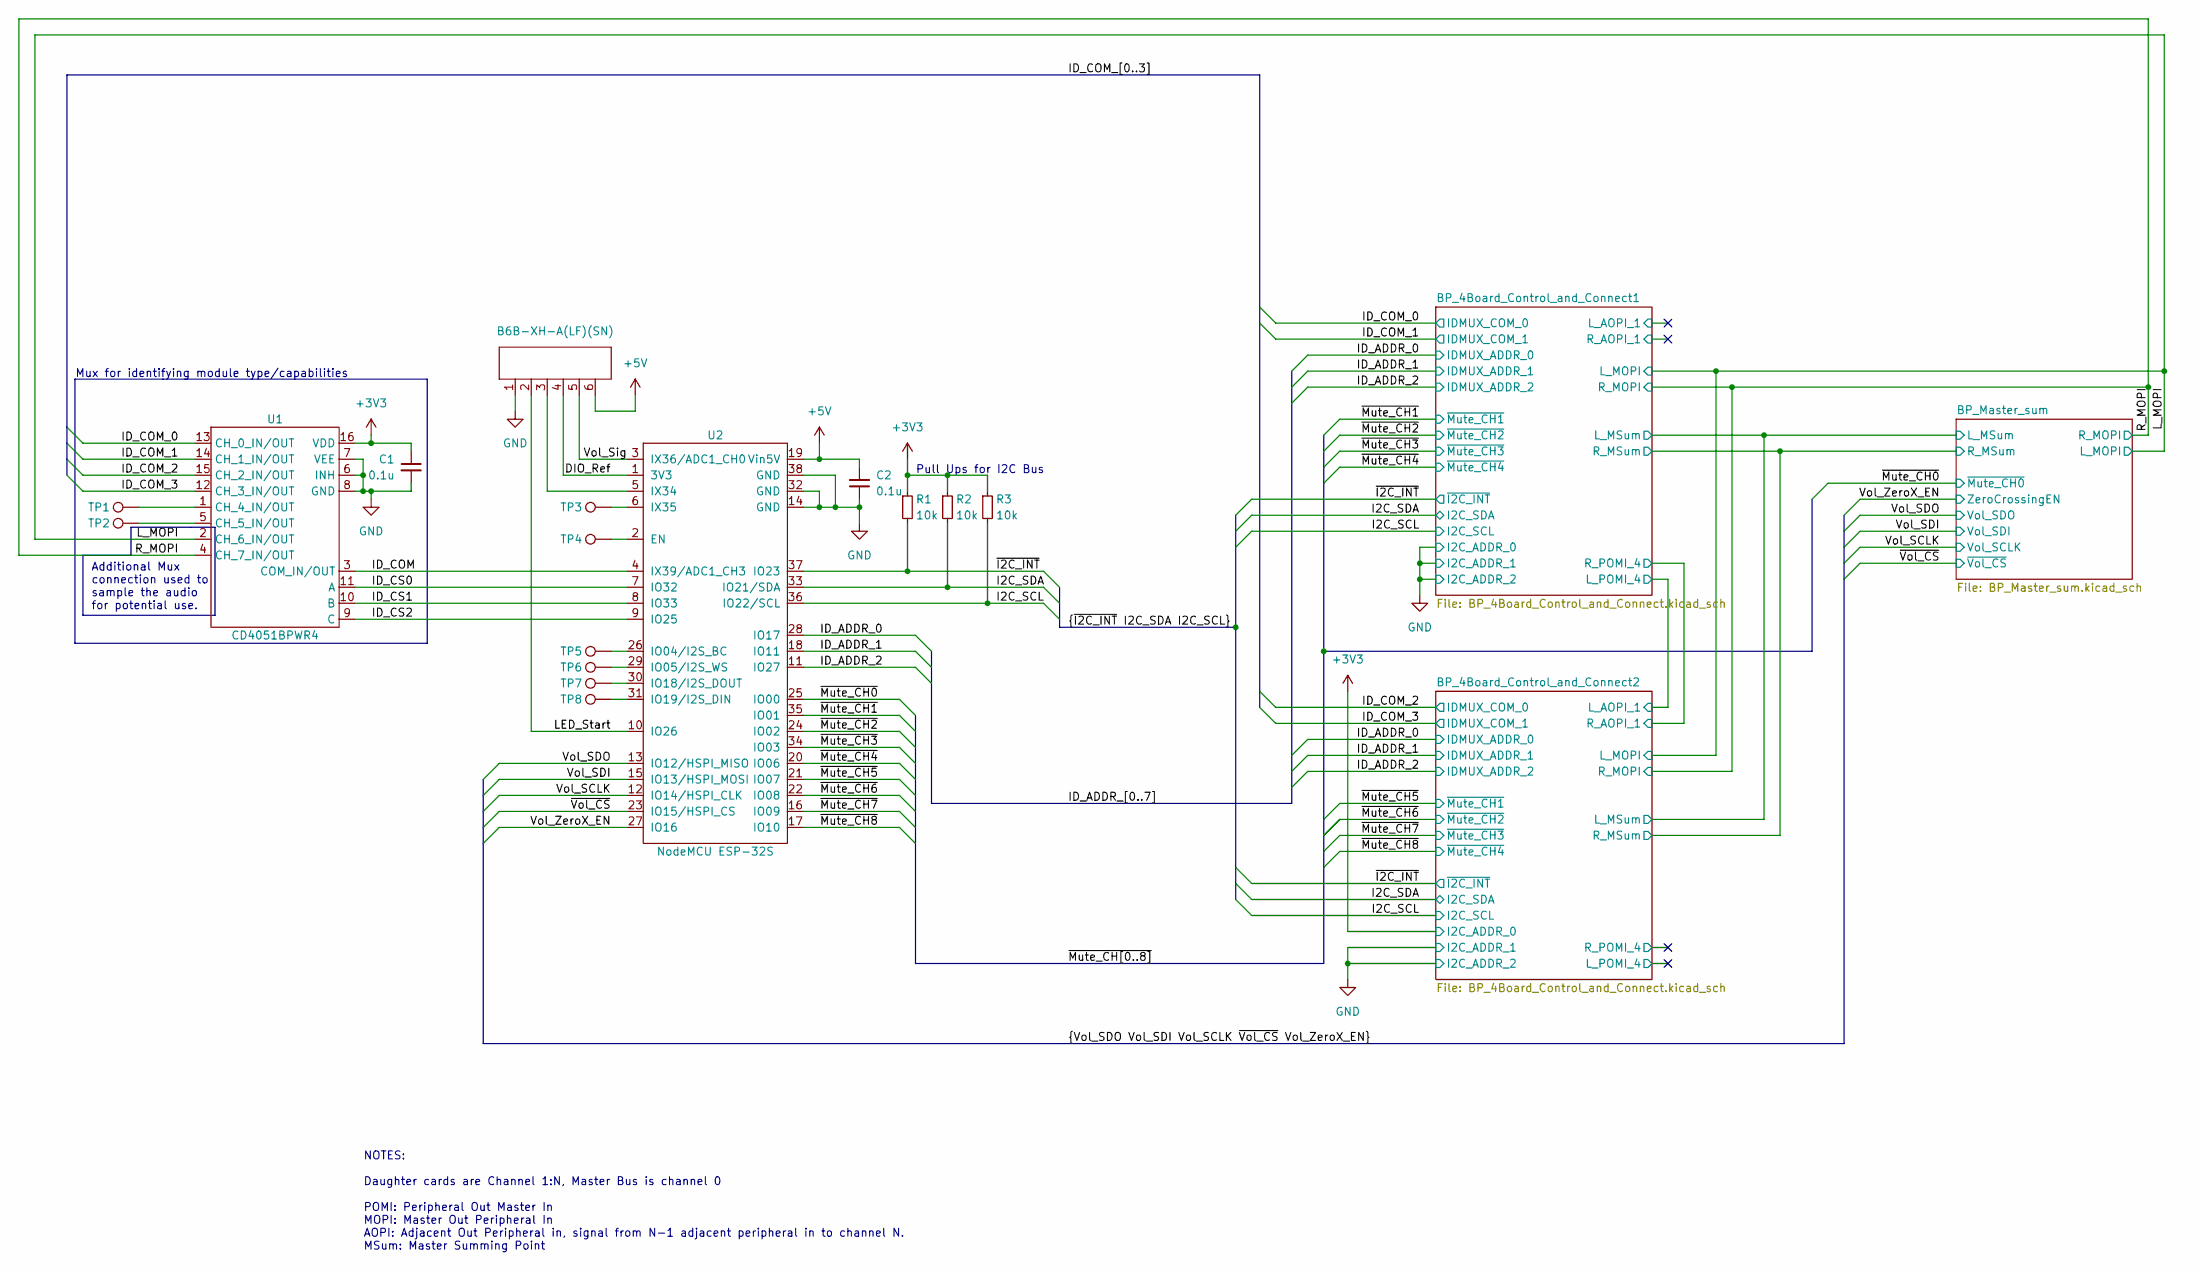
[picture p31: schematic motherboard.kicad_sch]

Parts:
C1, C2: 0.1u; C_0603_1608Metric_Pad1.08x0.95mm_HandSolder; MPN C0603C104M5RACTU
J1: B6B-XH-A(LF)(SN); MPN B6B-XH-A(LF)(SN)
R1, R2, R3: 10k; R_0603_1608Metric_Pad0.98x0.95mm_HandSolder; MPN RC0603JR-1010KL
TP1, TP2, TP3, TP4, TP5, TP6, TP7, TP8: TestPoint; TestPoint_Pad_D3.0mm
U1: CD4051BPWR4; CD4051BPWR; MPN CD4051BPWR
U2: NodeMCU ESP-32S

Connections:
+3V3: C1.1, R1.1, R2.1, R3.1, U1.16 (VDD); also elsewhere on the board
+5V: C2.2, J1.6, U2.19 (Vin5V); also elsewhere on the board
/DIO_Ref: J1.4, U2.1 (3V3)
/I2C_SCL: R3.2, U2.36 (IO22/SCL); also elsewhere on the board
/I2C_SDA: R2.2, U2.33 (IO21/SDA); also elsewhere on the board
/ID_ADDR_0: U2.28 (IO17); also elsewhere on the board
/ID_ADDR_1: U2.18 (IO11); also elsewhere on the board
/ID_ADDR_2: U2.11 (IO27); also elsewhere on the board
/ID_COM: U1.3 (COM_IN/OUT), U2.4 (IX39/ADC1_CH3)
/ID_COM_0: U1.13 (CH_0_IN/OUT); also elsewhere on the board
/ID_COM_1: U1.14 (CH_1_IN/OUT); also elsewhere on the board
/ID_COM_2: U1.15 (CH_2_IN/OUT); also elsewhere on the board
/ID_COM_3: U1.12 (CH_3_IN/OUT); also elsewhere on the board
/ID_CS0: U1.11 (A), U2.7 (IO32)
/ID_CS1: U1.10 (B), U2.8 (IO33)
/ID_CS2: U1.9 (C), U2.9 (IO25)
/LED_Start: J1.2, U2.10 (IO26)
/L_MOPI: U1.2 (CH_6_IN/OUT); also elsewhere on the board
/R_MOPI: U1.4 (CH_7_IN/OUT); also elsewhere on the board
/Vol_SCLK: U2.12 (IO14/HSPI_CLK); also elsewhere on the board
/Vol_SDI: U2.15 (IO13/HSPI_MOSI); also elsewhere on the board
/Vol_SDO: U2.13 (IO12/HSPI_MISO); also elsewhere on the board
/Vol_Sig: J1.5, U2.3 (IX36/ADC1_CH0)
/Vol_ZeroX_EN: U2.27 (IO16); also elsewhere on the board
/~I2C_INT: R1.2, U2.37 (IO23); also elsewhere on the board
/~Mute_CH0: U2.25 (IO00); also elsewhere on the board
/~Mute_CH1: U2.35 (IO01); also elsewhere on the board
/~Mute_CH2: U2.24 (IO02); also elsewhere on the board
/~Mute_CH3: U2.34 (IO03); also elsewhere on the board
/~Mute_CH4: U2.20 (IO06); also elsewhere on the board
/~Mute_CH5: U2.21 (IO07); also elsewhere on the board
/~Mute_CH6: U2.22 (IO08); also elsewhere on the board
/~Mute_CH7: U2.16 (IO09); also elsewhere on the board
/~Mute_CH8: U2.17 (IO10); also elsewhere on the board
/~Vol_CS: U2.23 (IO15/HSPI_CS); also elsewhere on the board
GND: C1.2, C2.1, J1.1, U1.6 (INH), U1.7 (VEE), U1.8 (GND), U2.14 (GND), U2.32 (GND), U2.38 (GND); also elsewhere on the board
unnamed: TP1.1, U1.1 (CH_4_IN/OUT)
unnamed: TP2.1, U1.5 (CH_5_IN/OUT)
unnamed: TP4.1, U2.2 (EN)
unnamed: TP5.1, U2.26 (IO04/I2S_BC)
unnamed: TP6.1, U2.29 (IO05/I2S_WS)
unnamed: TP7.1, U2.30 (IO18/I2S_DOUT)
unnamed: TP8.1, U2.31 (IO19/I2S_DIN)
unnamed: J1.3, U2.5 (IX34)
unnamed: TP3.1, U2.6 (IX35)

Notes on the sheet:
Pull Ups for I2C Bus
NOTES: Daughter cards are Channel 1:N, Master Bus is channel 0 POMI: Peripheral Out Master In MOPI: Master Out Peripheral In AOPI: Adjacent Out Peripheral in, signal from N-1 adjacent peripheral in to channel N. MSum: Master Summing Point
Mux for identifying module type/capabilities
Additional Mux connection used to sample the audio for potential use.

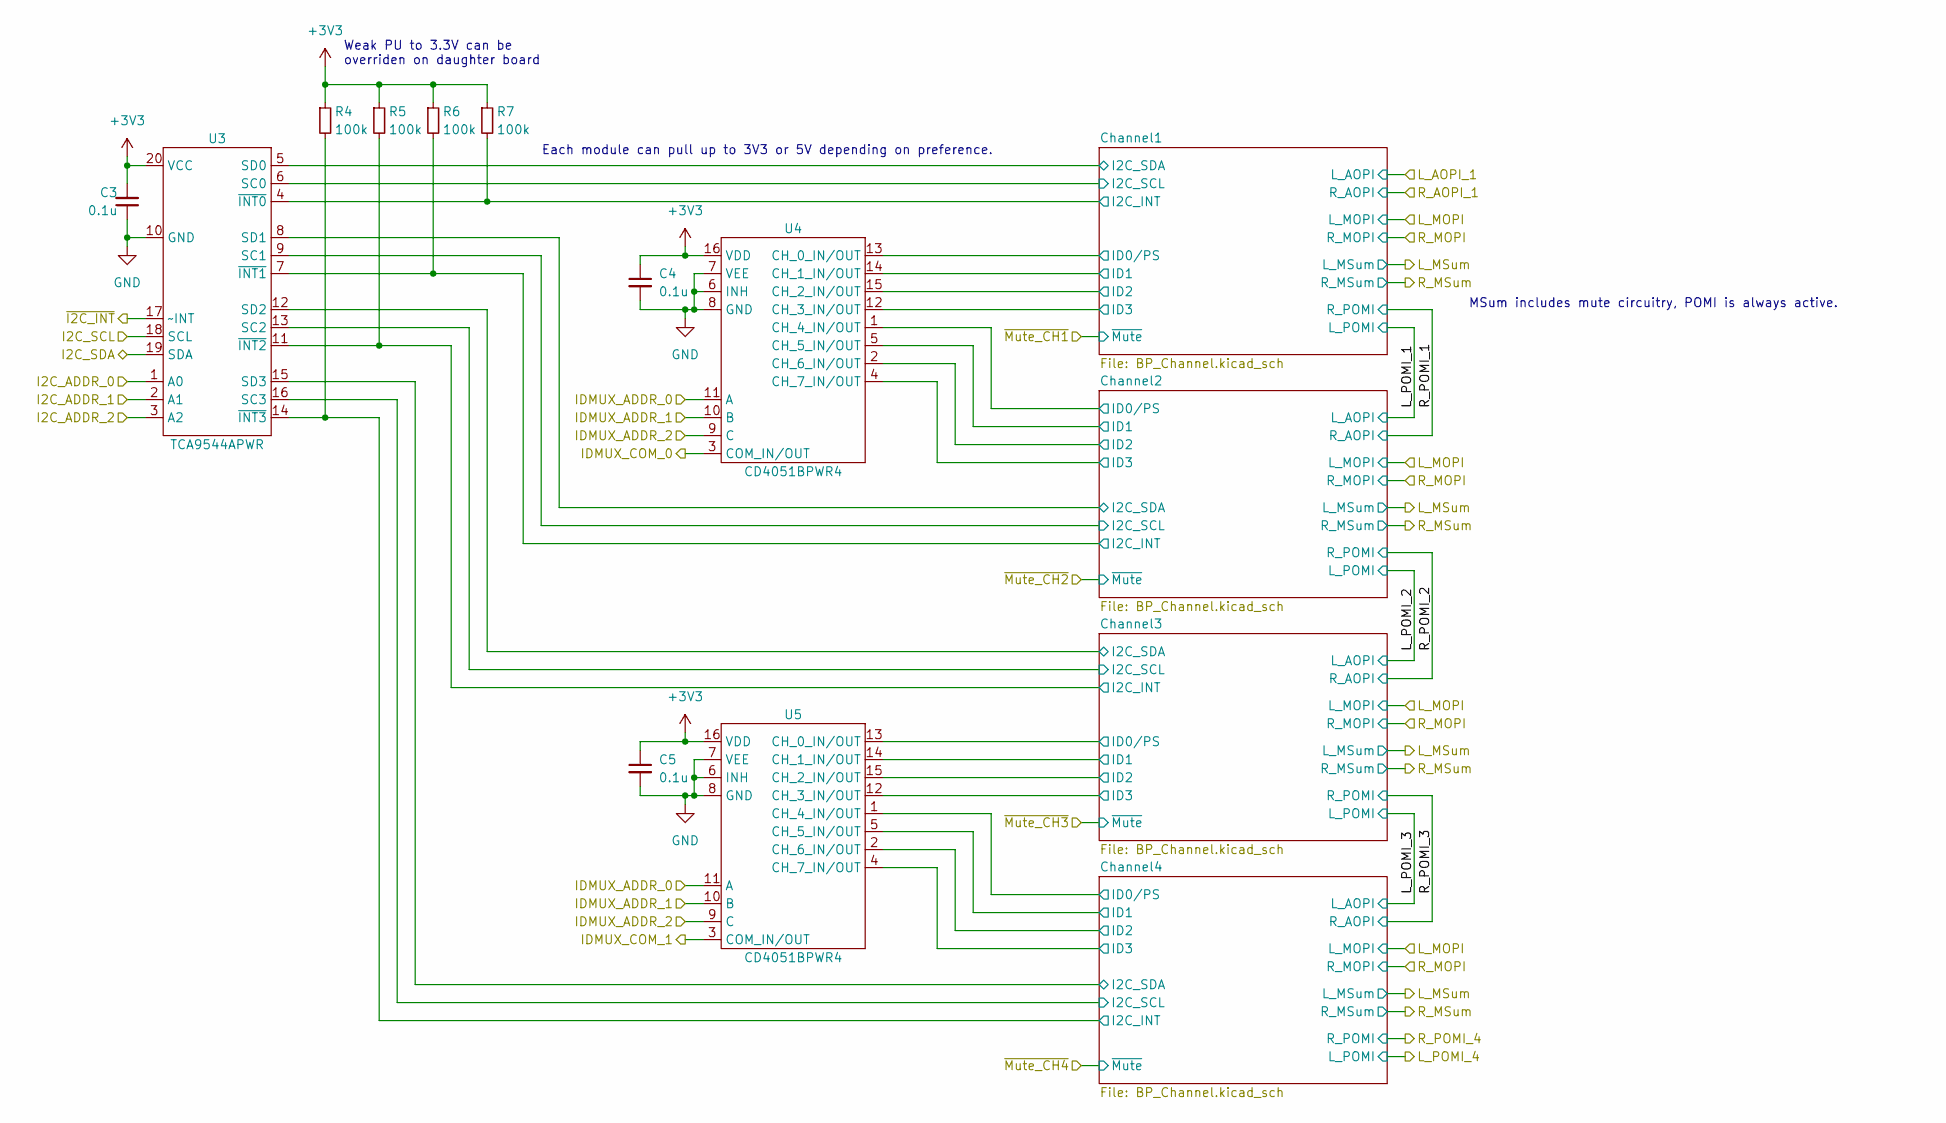
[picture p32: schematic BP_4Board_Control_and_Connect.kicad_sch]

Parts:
C3, C4, C5: 0.1u; C_0603_1608Metric_Pad1.08x0.95mm_HandSolder; MPN C0603C104M5RACTU
R4, R5, R6, R7: 100k; R_0603_1608Metric_Pad0.98x0.95mm_HandSolder; MPN C0603FR-07100KL
U3: TCA9544APWR; TCA9544AAPWR; MPN TCA9544APWR
U4, U5: CD4051BPWR4; CD4051BPWR; MPN CD4051BPWR

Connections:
+3V3: C3.2, C4.1, C5.1, R4.1, R5.1, R6.1, R7.1, U3.20 (VCC), U4.16 (VDD), U5.16 (VDD); also elsewhere on the board
/BP_4Board_Control_and_Connect1/Channel1/I2C_INT: R7.2, U3.4 (~INT0); also elsewhere on the board
/BP_4Board_Control_and_Connect1/Channel1/I2C_SCL: U3.6 (SC0); also elsewhere on the board
/BP_4Board_Control_and_Connect1/Channel1/I2C_SDA: U3.5 (SD0); also elsewhere on the board
/BP_4Board_Control_and_Connect1/Channel1/ID0/PS: U4.13 (CH_0_IN/OUT); also elsewhere on the board
/BP_4Board_Control_and_Connect1/Channel1/ID1: U4.14 (CH_1_IN/OUT); also elsewhere on the board
/BP_4Board_Control_and_Connect1/Channel1/ID2: U4.15 (CH_2_IN/OUT); also elsewhere on the board
/BP_4Board_Control_and_Connect1/Channel1/ID3: U4.12 (CH_3_IN/OUT); also elsewhere on the board
/BP_4Board_Control_and_Connect1/Channel2/I2C_INT: R6.2, U3.7 (~INT1); also elsewhere on the board
/BP_4Board_Control_and_Connect1/Channel2/I2C_SCL: U3.9 (SC1); also elsewhere on the board
/BP_4Board_Control_and_Connect1/Channel2/I2C_SDA: U3.8 (SD1); also elsewhere on the board
/BP_4Board_Control_and_Connect1/Channel2/ID0/PS: U4.1 (CH_4_IN/OUT); also elsewhere on the board
/BP_4Board_Control_and_Connect1/Channel2/ID1: U4.5 (CH_5_IN/OUT); also elsewhere on the board
/BP_4Board_Control_and_Connect1/Channel2/ID2: U4.2 (CH_6_IN/OUT); also elsewhere on the board
/BP_4Board_Control_and_Connect1/Channel2/ID3: U4.4 (CH_7_IN/OUT); also elsewhere on the board
/BP_4Board_Control_and_Connect1/Channel3/I2C_INT: R5.2, U3.11 (~INT2); also elsewhere on the board
/BP_4Board_Control_and_Connect1/Channel3/I2C_SCL: U3.13 (SC2); also elsewhere on the board
/BP_4Board_Control_and_Connect1/Channel3/I2C_SDA: U3.12 (SD2); also elsewhere on the board
/BP_4Board_Control_and_Connect1/Channel3/ID0/PS: U5.13 (CH_0_IN/OUT); also elsewhere on the board
/BP_4Board_Control_and_Connect1/Channel3/ID1: U5.14 (CH_1_IN/OUT); also elsewhere on the board
/BP_4Board_Control_and_Connect1/Channel3/ID2: U5.15 (CH_2_IN/OUT); also elsewhere on the board
/BP_4Board_Control_and_Connect1/Channel3/ID3: U5.12 (CH_3_IN/OUT); also elsewhere on the board
/BP_4Board_Control_and_Connect1/Channel4/I2C_INT: R4.2, U3.14 (~INT3); also elsewhere on the board
/BP_4Board_Control_and_Connect1/Channel4/I2C_SCL: U3.16 (SC3); also elsewhere on the board
/BP_4Board_Control_and_Connect1/Channel4/I2C_SDA: U3.15 (SD3); also elsewhere on the board
/BP_4Board_Control_and_Connect1/Channel4/ID0/PS: U5.1 (CH_4_IN/OUT); also elsewhere on the board
/BP_4Board_Control_and_Connect1/Channel4/ID1: U5.5 (CH_5_IN/OUT); also elsewhere on the board
/BP_4Board_Control_and_Connect1/Channel4/ID2: U5.2 (CH_6_IN/OUT); also elsewhere on the board
/BP_4Board_Control_and_Connect1/Channel4/ID3: U5.4 (CH_7_IN/OUT); also elsewhere on the board
/I2C_SCL: U3.18 (SCL); also elsewhere on the board
/I2C_SDA: U3.19 (SDA); also elsewhere on the board
/ID_ADDR_0: U4.11 (A), U5.11 (A); also elsewhere on the board
/ID_ADDR_1: U4.10 (B), U5.10 (B); also elsewhere on the board
/ID_ADDR_2: U4.9 (C), U5.9 (C); also elsewhere on the board
/ID_COM_0: U4.3 (COM_IN/OUT); also elsewhere on the board
/ID_COM_1: U5.3 (COM_IN/OUT); also elsewhere on the board
/~I2C_INT: U3.17 (~INT); also elsewhere on the board
GND: C3.1, C4.2, C5.2, U3.1 (A0), U3.2 (A1), U3.3 (A2), U3.10 (GND), U4.6 (INH), U4.7 (VEE), U4.8 (GND), U5.6 (INH), U5.7 (VEE), U5.8 (GND); also elsewhere on the board

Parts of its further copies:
C22, C23, C24: 0.1u; C_0603_1608Metric_Pad1.08x0.95mm_HandSolder; MPN C0603C104M5RACTU
R48, R49, R50, R51: 100k; R_0603_1608Metric_Pad0.98x0.95mm_HandSolder; MPN C0603FR-07100KL
U18: TCA9544APWR; TCA9544AAPWR; MPN TCA9544APWR
U19, U20: CD4051BPWR4; CD4051BPWR; MPN CD4051BPWR

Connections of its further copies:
+3V3: C22.2, C23.1, C24.1, R48.1, R49.1, R50.1, R51.1, U18.1 (A0), U18.20 (VCC), U19.16 (VDD), U20.16 (VDD); also elsewhere on the board
/BP_4Board_Control_and_Connect2/Channel1/I2C_INT: R51.2, U18.4 (~INT0); also elsewhere on the board
/BP_4Board_Control_and_Connect2/Channel1/I2C_SCL: U18.6 (SC0); also elsewhere on the board
/BP_4Board_Control_and_Connect2/Channel1/I2C_SDA: U18.5 (SD0); also elsewhere on the board
/BP_4Board_Control_and_Connect2/Channel1/ID0/PS: U19.13 (CH_0_IN/OUT); also elsewhere on the board
/BP_4Board_Control_and_Connect2/Channel1/ID1: U19.14 (CH_1_IN/OUT); also elsewhere on the board
/BP_4Board_Control_and_Connect2/Channel1/ID2: U19.15 (CH_2_IN/OUT); also elsewhere on the board
/BP_4Board_Control_and_Connect2/Channel1/ID3: U19.12 (CH_3_IN/OUT); also elsewhere on the board
/BP_4Board_Control_and_Connect2/Channel2/I2C_INT: R50.2, U18.7 (~INT1); also elsewhere on the board
/BP_4Board_Control_and_Connect2/Channel2/I2C_SCL: U18.9 (SC1); also elsewhere on the board
/BP_4Board_Control_and_Connect2/Channel2/I2C_SDA: U18.8 (SD1); also elsewhere on the board
/BP_4Board_Control_and_Connect2/Channel2/ID0/PS: U19.1 (CH_4_IN/OUT); also elsewhere on the board
/BP_4Board_Control_and_Connect2/Channel2/ID1: U19.5 (CH_5_IN/OUT); also elsewhere on the board
/BP_4Board_Control_and_Connect2/Channel2/ID2: U19.2 (CH_6_IN/OUT); also elsewhere on the board
/BP_4Board_Control_and_Connect2/Channel2/ID3: U19.4 (CH_7_IN/OUT); also elsewhere on the board
/BP_4Board_Control_and_Connect2/Channel3/I2C_INT: R49.2, U18.11 (~INT2); also elsewhere on the board
/BP_4Board_Control_and_Connect2/Channel3/I2C_SCL: U18.13 (SC2); also elsewhere on the board
/BP_4Board_Control_and_Connect2/Channel3/I2C_SDA: U18.12 (SD2); also elsewhere on the board
/BP_4Board_Control_and_Connect2/Channel3/ID0/PS: U20.13 (CH_0_IN/OUT); also elsewhere on the board
/BP_4Board_Control_and_Connect2/Channel3/ID1: U20.14 (CH_1_IN/OUT); also elsewhere on the board
/BP_4Board_Control_and_Connect2/Channel3/ID2: U20.15 (CH_2_IN/OUT); also elsewhere on the board
/BP_4Board_Control_and_Connect2/Channel3/ID3: U20.12 (CH_3_IN/OUT); also elsewhere on the board
/BP_4Board_Control_and_Connect2/Channel4/I2C_INT: R48.2, U18.14 (~INT3); also elsewhere on the board
/BP_4Board_Control_and_Connect2/Channel4/I2C_SCL: U18.16 (SC3); also elsewhere on the board
/BP_4Board_Control_and_Connect2/Channel4/I2C_SDA: U18.15 (SD3); also elsewhere on the board
/BP_4Board_Control_and_Connect2/Channel4/ID0/PS: U20.1 (CH_4_IN/OUT); also elsewhere on the board
/BP_4Board_Control_and_Connect2/Channel4/ID1: U20.5 (CH_5_IN/OUT); also elsewhere on the board
/BP_4Board_Control_and_Connect2/Channel4/ID2: U20.2 (CH_6_IN/OUT); also elsewhere on the board
/BP_4Board_Control_and_Connect2/Channel4/ID3: U20.4 (CH_7_IN/OUT); also elsewhere on the board
/I2C_SCL: U18.18 (SCL); also elsewhere on the board
/I2C_SDA: U18.19 (SDA); also elsewhere on the board
/ID_ADDR_0: U19.11 (A), U20.11 (A); also elsewhere on the board
/ID_ADDR_1: U19.10 (B), U20.10 (B); also elsewhere on the board
/ID_ADDR_2: U19.9 (C), U20.9 (C); also elsewhere on the board
/ID_COM_2: U19.3 (COM_IN/OUT); also elsewhere on the board
/ID_COM_3: U20.3 (COM_IN/OUT); also elsewhere on the board
/~I2C_INT: U18.17 (~INT); also elsewhere on the board
GND: C22.1, C23.2, C24.2, U18.2 (A1), U18.3 (A2), U18.10 (GND), U19.6 (INH), U19.7 (VEE), U19.8 (GND), U20.6 (INH), U20.7 (VEE), U20.8 (GND); also elsewhere on the board

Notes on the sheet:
MSum includes mute circuitry, POMI is always active.
Weak PU to 3.3V can be overriden on daughter board
Each module can pull up to 3V3 or 5V depending on preference.

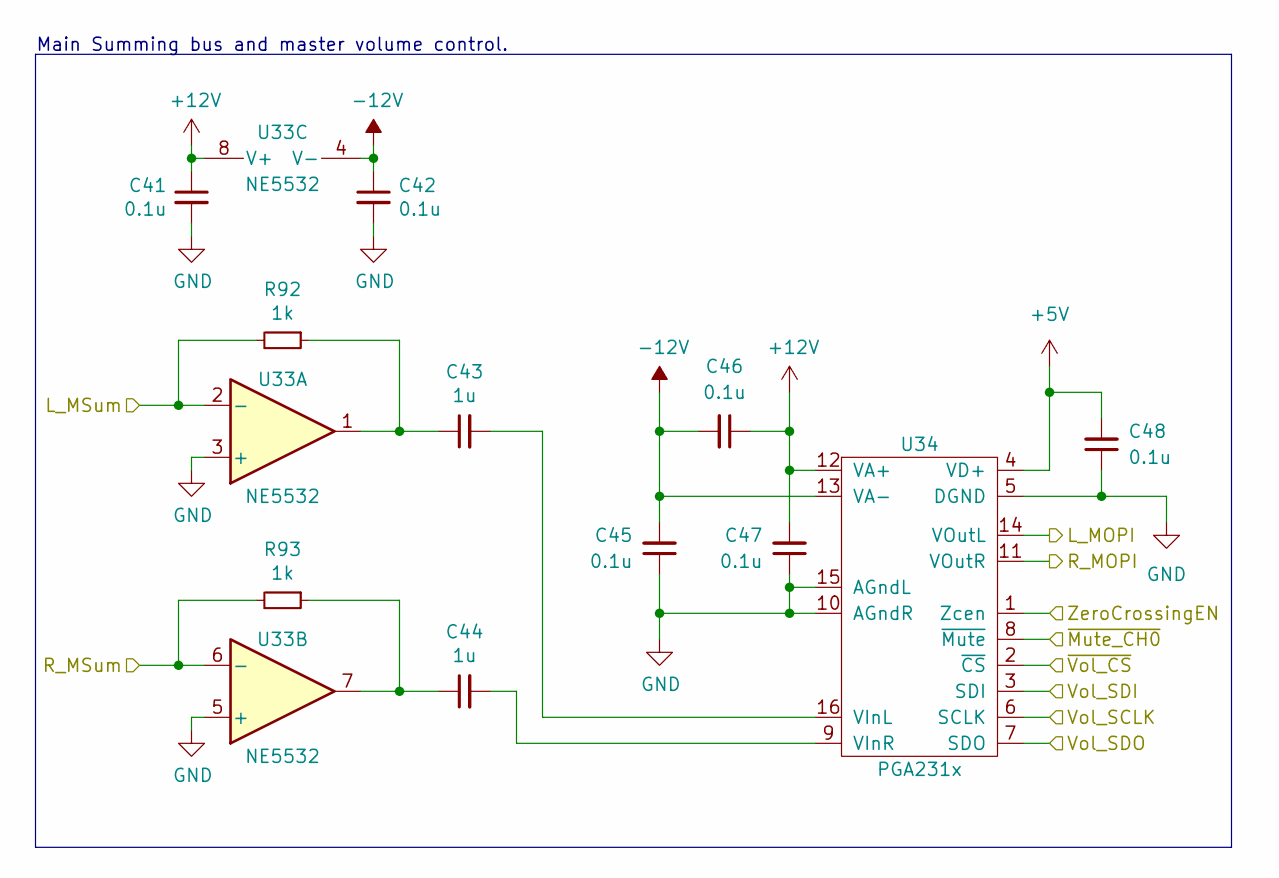
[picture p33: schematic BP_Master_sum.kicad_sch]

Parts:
C41, C42, C45, C46, C47, C48: 0.1u; C_0603_1608Metric_Pad1.08x0.95mm_HandSolder; MPN C0603C104M5RACTU
C43, C44: 1u; C_2220_5650Metric_Pad1.97x5.40mm_HandSolder; MPN GRM55DR72E105KW01L
R92, R93: 1k; R_0603_1608Metric_Pad0.98x0.95mm_HandSolder; MPN RT0603FRE071KL
U33: NE5532; NE5532 SOIC8; MPN NE5532ADR
U34: PGA231x; PGA231XU; MPN PGA2310UA/1K

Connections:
+5V: C48.2, U34.4 (VD+); also elsewhere on the board
+12V: C41.1, C46.1, C47.2, U33.8 (V+), U34.12 (VA+); also elsewhere on the board
-12V: C42.1, C45.2, C46.2, U33.4 (V-), U34.13 (VA-); also elsewhere on the board
/BP_4Board_Control_and_Connect1/L_MSum: R92.2, U33.2 (-); also elsewhere on the board
/BP_4Board_Control_and_Connect1/R_MSum: R93.2, U33.6 (-); also elsewhere on the board
/L_MOPI: U34.14 (VOutL); also elsewhere on the board
/R_MOPI: U34.11 (VOutR); also elsewhere on the board
/Vol_SCLK: U34.6 (SCLK); also elsewhere on the board
/Vol_SDI: U34.3 (SDI); also elsewhere on the board
/Vol_SDO: U34.7 (SDO); also elsewhere on the board
/Vol_ZeroX_EN: U34.1 (Zcen); also elsewhere on the board
/~Mute_CH0: U34.8 (~Mute); also elsewhere on the board
/~Vol_CS: U34.2 (~CS); also elsewhere on the board
GND: C41.2, C42.2, C45.1, C47.1, C48.1, U33.3 (+), U33.5 (+), U34.5 (DGND), U34.10 (AGndR), U34.15 (AGndL); also elsewhere on the board
unnamed: C43.1, R92.1, U33.1
unnamed: C44.1, R93.1, U33.7
unnamed: C43.2, U34.16 (VInL)
unnamed: C44.2, U34.9 (VInR)

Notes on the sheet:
Main Summing bus and master volume control.

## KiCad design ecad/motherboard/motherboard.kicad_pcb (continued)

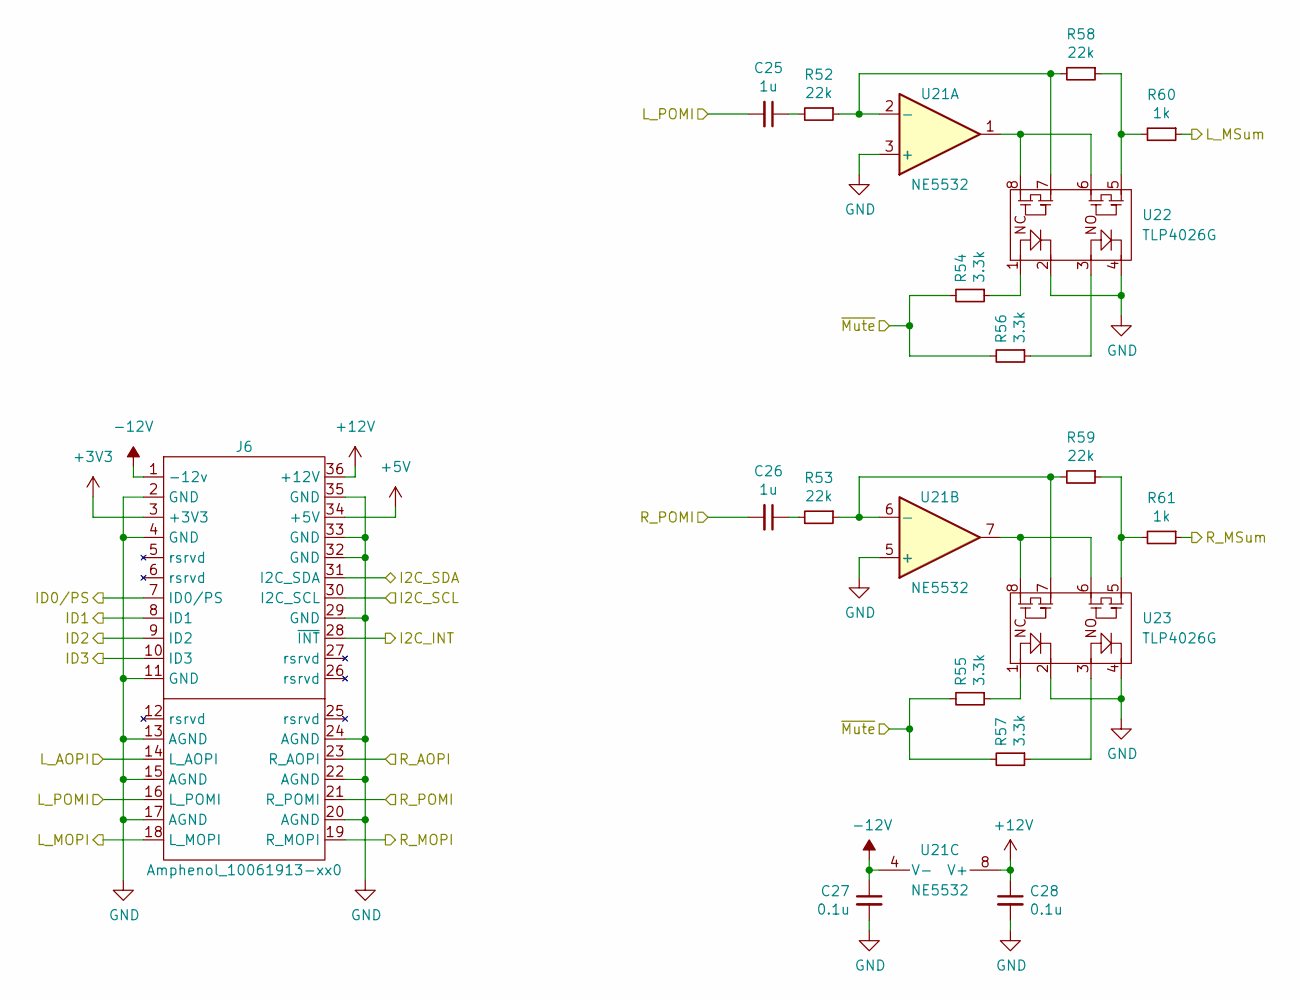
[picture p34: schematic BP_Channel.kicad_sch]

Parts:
C25, C26: 1u; C_2220_5650Metric_Pad1.97x5.40mm_HandSolder; MPN GRM55DR72E105KW01L
C27, C28: 0.1u; C_0603_1608Metric_Pad1.08x0.95mm_HandSolder; MPN C0603C104M5RACTU
J6: Amphenol_10061913-xx0; Card Edge Conn Amphenol 10061913-100PLF; MPN 10061913-110PLF
R52, R53, R58, R59: 22k; R_0603_1608Metric_Pad0.98x0.95mm_HandSolder; MPN RT0603FRE0722KL
R54, R55, R56, R57: 3.3k; R_0603_1608Metric_Pad0.98x0.95mm_HandSolder; MPN RC0603FR-073K3L
R60, R61: 1k; R_0603_1608Metric_Pad0.98x0.95mm_HandSolder; MPN RT0603FRE071KL
U21: NE5532; NE5532 SOIC8; MPN NE5532ADR
U22, U23: TLP4026G; MPN CPC2317NTR

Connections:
+3V3: J6.3 (+3V3); also elsewhere on the board
+5V: J6.34 (+5V); also elsewhere on the board
+12V: C28.1, J6.36 (+12V), U21.8 (V+); also elsewhere on the board
-12V: C27.1, J6.1 (-12v), U21.4 (V-); also elsewhere on the board
/BP_4Board_Control_and_Connect1/L_MSum: R60.1; also elsewhere on the board
/BP_4Board_Control_and_Connect1/L_POMI_4: J6.14 (L_AOPI); also elsewhere on the board
/BP_4Board_Control_and_Connect1/R_MSum: R61.1; also elsewhere on the board
/BP_4Board_Control_and_Connect1/R_POMI_4: J6.23 (R_AOPI); also elsewhere on the board
/BP_4Board_Control_and_Connect2/Channel1/I2C_INT: J6.28 (~INT); also elsewhere on the board
/BP_4Board_Control_and_Connect2/Channel1/I2C_SCL: J6.30 (I2C_SCL); also elsewhere on the board
/BP_4Board_Control_and_Connect2/Channel1/I2C_SDA: J6.31 (I2C_SDA); also elsewhere on the board
/BP_4Board_Control_and_Connect2/Channel1/ID0/PS: J6.7 (ID0/PS); also elsewhere on the board
/BP_4Board_Control_and_Connect2/Channel1/ID1: J6.8 (ID1); also elsewhere on the board
/BP_4Board_Control_and_Connect2/Channel1/ID2: J6.9 (ID2); also elsewhere on the board
/BP_4Board_Control_and_Connect2/Channel1/ID3: J6.10 (ID3); also elsewhere on the board
/BP_4Board_Control_and_Connect2/L_POMI_1: C25.2, J6.16 (L_POMI); also elsewhere on the board
/BP_4Board_Control_and_Connect2/R_POMI_1: C26.2, J6.21 (R_POMI); also elsewhere on the board
/L_MOPI: J6.18 (L_MOPI); also elsewhere on the board
/R_MOPI: J6.19 (R_MOPI); also elsewhere on the board
/~Mute_CH5: R54.2, R55.2, R56.2, R57.2; also elsewhere on the board
GND: C27.2, C28.2, J6.2 (GND), J6.4 (GND), J6.11 (GND), J6.13 (AGND), J6.15 (AGND), J6.17 (AGND), J6.20 (AGND), J6.22 (AGND), J6.24 (AGND), J6.29 (GND), J6.32 (GND), J6.33 (GND), J6.35 (GND), U21.3 (+), U21.5 (+), U22.2, U22.4, U23.2, U23.4; also elsewhere on the board
unnamed: C25.1, R52.2
unnamed: C26.1, R53.2
unnamed: R54.1, U22.1
unnamed: R55.1, U23.1
unnamed: R56.1, U22.3
unnamed: R57.1, U23.3
unnamed: R58.1, R60.2, U22.5
unnamed: R59.1, R61.2, U23.5
unnamed: U21.1, U22.6, U22.8
unnamed: U21.7, U23.6, U23.8
unnamed: R52.1, R58.2, U21.2 (-), U22.7
unnamed: R53.1, R59.2, U21.6 (-), U23.7

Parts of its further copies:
C6, C7, C10, C11, C14, C15, C18, C19, C29, C30, C33, C34, C37, C38: 1u; C_2220_5650Metric_Pad1.97x5.40mm_HandSolder; MPN GRM55DR72E105KW01L
C8, C9, C12, C13, C16, C17, C20, C21, C31, C32, C35, C36, C39, C40: 0.1u; C_0603_1608Metric_Pad1.08x0.95mm_HandSolder; MPN C0603C104M5RACTU
J2, J3, J4, J5, J7, J8, J9: Amphenol_10061913-xx0; Card Edge Conn Amphenol 10061913-100PLF; MPN 10061913-110PLF
R8, R9, R14, R15, R18, R19, R24, R25, R28, R29, R34, R35, R38, R39, R44, R45, R62, R63, R68, R69, R72, R73, R78, R79, R82, R83, R88, R89: 22k; R_0603_1608Metric_Pad0.98x0.95mm_HandSolder; MPN RT0603FRE0722KL
R10, R11, R12, R13, R20, R21, R22, R23, R30, R31, R32, R33, R40, R41, R42, R43, R64, R65, R66, R67, R74, R75, R76, R77, R84, R85, R86, R87: 3.3k; R_0603_1608Metric_Pad0.98x0.95mm_HandSolder; MPN RC0603FR-073K3L
R16, R17, R26, R27, R36, R37, R46, R47, R70, R71, R80, R81, R90, R91: 1k; R_0603_1608Metric_Pad0.98x0.95mm_HandSolder; MPN RT0603FRE071KL
U6, U9, U12, U15, U24, U27, U30: NE5532; NE5532 SOIC8; MPN NE5532ADR
U7, U8, U10, U11, U13, U14, U16, U17, U25, U26, U28, U29, U31, U32: TLP4026G; MPN CPC2317NTR

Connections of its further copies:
+3V3: J2.3 (+3V3), J3.3 (+3V3), J4.3 (+3V3), J5.3 (+3V3), J7.3 (+3V3), J8.3 (+3V3), J9.3 (+3V3); also elsewhere on the board
+5V: J2.34 (+5V), J3.34 (+5V), J4.34 (+5V), J5.34 (+5V), J7.34 (+5V), J8.34 (+5V), J9.34 (+5V); also elsewhere on the board
+12V: C9.1, C13.1, C17.1, C21.1, C32.1, C36.1, C40.1, J2.36 (+12V), J3.36 (+12V), J4.36 (+12V), J5.36 (+12V), J7.36 (+12V), J8.36 (+12V), J9.36 (+12V), U6.8 (V+), U9.8 (V+), U12.8 (V+), U15.8 (V+), U24.8 (V+), U27.8 (V+), U30.8 (V+); also elsewhere on the board
-12V: C8.1, C12.1, C16.1, C20.1, C31.1, C35.1, C39.1, J2.1 (-12v), J3.1 (-12v), J4.1 (-12v), J5.1 (-12v), J7.1 (-12v), J8.1 (-12v), J9.1 (-12v), U6.4 (V-), U9.4 (V-), U12.4 (V-), U15.4 (V-), U24.4 (V-), U27.4 (V-), U30.4 (V-); also elsewhere on the board
/BP_4Board_Control_and_Connect1/Channel1/I2C_INT: J2.28 (~INT); also elsewhere on the board
/BP_4Board_Control_and_Connect1/Channel1/I2C_SCL: J2.30 (I2C_SCL); also elsewhere on the board
/BP_4Board_Control_and_Connect1/Channel1/I2C_SDA: J2.31 (I2C_SDA); also elsewhere on the board
/BP_4Board_Control_and_Connect1/Channel1/ID0/PS: J2.7 (ID0/PS); also elsewhere on the board
/BP_4Board_Control_and_Connect1/Channel1/ID1: J2.8 (ID1); also elsewhere on the board
/BP_4Board_Control_and_Connect1/Channel1/ID2: J2.9 (ID2); also elsewhere on the board
/BP_4Board_Control_and_Connect1/Channel1/ID3: J2.10 (ID3); also elsewhere on the board
/BP_4Board_Control_and_Connect1/Channel2/I2C_INT: J3.28 (~INT); also elsewhere on the board
/BP_4Board_Control_and_Connect1/Channel2/I2C_SCL: J3.30 (I2C_SCL); also elsewhere on the board
/BP_4Board_Control_and_Connect1/Channel2/I2C_SDA: J3.31 (I2C_SDA); also elsewhere on the board
/BP_4Board_Control_and_Connect1/Channel2/ID0/PS: J3.7 (ID0/PS); also elsewhere on the board
/BP_4Board_Control_and_Connect1/Channel2/ID1: J3.8 (ID1); also elsewhere on the board
/BP_4Board_Control_and_Connect1/Channel2/ID2: J3.9 (ID2); also elsewhere on the board
/BP_4Board_Control_and_Connect1/Channel2/ID3: J3.10 (ID3); also elsewhere on the board
/BP_4Board_Control_and_Connect1/Channel3/I2C_INT: J4.28 (~INT); also elsewhere on the board
/BP_4Board_Control_and_Connect1/Channel3/I2C_SCL: J4.30 (I2C_SCL); also elsewhere on the board
/BP_4Board_Control_and_Connect1/Channel3/I2C_SDA: J4.31 (I2C_SDA); also elsewhere on the board
/BP_4Board_Control_and_Connect1/Channel3/ID0/PS: J4.7 (ID0/PS); also elsewhere on the board
/BP_4Board_Control_and_Connect1/Channel3/ID1: J4.8 (ID1); also elsewhere on the board
/BP_4Board_Control_and_Connect1/Channel3/ID2: J4.9 (ID2); also elsewhere on the board
/BP_4Board_Control_and_Connect1/Channel3/ID3: J4.10 (ID3); also elsewhere on the board
/BP_4Board_Control_and_Connect1/Channel4/I2C_INT: J5.28 (~INT); also elsewhere on the board
/BP_4Board_Control_and_Connect1/Channel4/I2C_SCL: J5.30 (I2C_SCL); also elsewhere on the board
/BP_4Board_Control_and_Connect1/Channel4/I2C_SDA: J5.31 (I2C_SDA); also elsewhere on the board
/BP_4Board_Control_and_Connect1/Channel4/ID0/PS: J5.7 (ID0/PS); also elsewhere on the board
/BP_4Board_Control_and_Connect1/Channel4/ID1: J5.8 (ID1); also elsewhere on the board
/BP_4Board_Control_and_Connect1/Channel4/ID2: J5.9 (ID2); also elsewhere on the board
/BP_4Board_Control_and_Connect1/Channel4/ID3: J5.10 (ID3); also elsewhere on the board
/BP_4Board_Control_and_Connect1/L_AOPI_1: J2.14 (L_AOPI)
/BP_4Board_Control_and_Connect1/L_MSum: R16.1, R26.1, R36.1, R46.1, R70.1, R80.1, R90.1; also elsewhere on the board
/BP_4Board_Control_and_Connect1/L_POMI_1: C6.2, J2.16 (L_POMI), J3.14 (L_AOPI)
/BP_4Board_Control_and_Connect1/L_POMI_2: C10.2, J3.16 (L_POMI), J4.14 (L_AOPI)
/BP_4Board_Control_and_Connect1/L_POMI_3: C14.2, J4.16 (L_POMI), J5.14 (L_AOPI)
/BP_4Board_Control_and_Connect1/L_POMI_4: C18.2, J5.16 (L_POMI); also elsewhere on the board
/BP_4Board_Control_and_Connect1/R_AOPI_1: J2.23 (R_AOPI)
/BP_4Board_Control_and_Connect1/R_MSum: R17.1, R27.1, R37.1, R47.1, R71.1, R81.1, R91.1; also elsewhere on the board
/BP_4Board_Control_and_Connect1/R_POMI_1: C7.2, J2.21 (R_POMI), J3.23 (R_AOPI)
/BP_4Board_Control_and_Connect1/R_POMI_2: C11.2, J3.21 (R_POMI), J4.23 (R_AOPI)
/BP_4Board_Control_and_Connect1/R_POMI_3: C15.2, J4.21 (R_POMI), J5.23 (R_AOPI)
/BP_4Board_Control_and_Connect1/R_POMI_4: C19.2, J5.21 (R_POMI); also elsewhere on the board
/BP_4Board_Control_and_Connect2/Channel2/I2C_INT: J7.28 (~INT); also elsewhere on the board
/BP_4Board_Control_and_Connect2/Channel2/I2C_SCL: J7.30 (I2C_SCL); also elsewhere on the board
/BP_4Board_Control_and_Connect2/Channel2/I2C_SDA: J7.31 (I2C_SDA); also elsewhere on the board
/BP_4Board_Control_and_Connect2/Channel2/ID0/PS: J7.7 (ID0/PS); also elsewhere on the board
/BP_4Board_Control_and_Connect2/Channel2/ID1: J7.8 (ID1); also elsewhere on the board
/BP_4Board_Control_and_Connect2/Channel2/ID2: J7.9 (ID2); also elsewhere on the board
/BP_4Board_Control_and_Connect2/Channel2/ID3: J7.10 (ID3); also elsewhere on the board
/BP_4Board_Control_and_Connect2/Channel3/I2C_INT: J8.28 (~INT); also elsewhere on the board
/BP_4Board_Control_and_Connect2/Channel3/I2C_SCL: J8.30 (I2C_SCL); also elsewhere on the board
/BP_4Board_Control_and_Connect2/Channel3/I2C_SDA: J8.31 (I2C_SDA); also elsewhere on the board
/BP_4Board_Control_and_Connect2/Channel3/ID0/PS: J8.7 (ID0/PS); also elsewhere on the board
/BP_4Board_Control_and_Connect2/Channel3/ID1: J8.8 (ID1); also elsewhere on the board
/BP_4Board_Control_and_Connect2/Channel3/ID2: J8.9 (ID2); also elsewhere on the board
/BP_4Board_Control_and_Connect2/Channel3/ID3: J8.10 (ID3); also elsewhere on the board
/BP_4Board_Control_and_Connect2/Channel4/I2C_INT: J9.28 (~INT); also elsewhere on the board
/BP_4Board_Control_and_Connect2/Channel4/I2C_SCL: J9.30 (I2C_SCL); also elsewhere on the board
/BP_4Board_Control_and_Connect2/Channel4/I2C_SDA: J9.31 (I2C_SDA); also elsewhere on the board
/BP_4Board_Control_and_Connect2/Channel4/ID0/PS: J9.7 (ID0/PS); also elsewhere on the board
/BP_4Board_Control_and_Connect2/Channel4/ID1: J9.8 (ID1); also elsewhere on the board
/BP_4Board_Control_and_Connect2/Channel4/ID2: J9.9 (ID2); also elsewhere on the board
/BP_4Board_Control_and_Connect2/Channel4/ID3: J9.10 (ID3); also elsewhere on the board
/BP_4Board_Control_and_Connect2/L_POMI_1: J7.14 (L_AOPI); also elsewhere on the board
/BP_4Board_Control_and_Connect2/L_POMI_2: C29.2, J7.16 (L_POMI), J8.14 (L_AOPI)
/BP_4Board_Control_and_Connect2/L_POMI_3: C33.2, J8.16 (L_POMI), J9.14 (L_AOPI)
/BP_4Board_Control_and_Connect2/L_POMI_4: C37.2, J9.16 (L_POMI)
/BP_4Board_Control_and_Connect2/R_POMI_1: J7.23 (R_AOPI); also elsewhere on the board
/BP_4Board_Control_and_Connect2/R_POMI_2: C30.2, J7.21 (R_POMI), J8.23 (R_AOPI)
/BP_4Board_Control_and_Connect2/R_POMI_3: C34.2, J8.21 (R_POMI), J9.23 (R_AOPI)
/BP_4Board_Control_and_Connect2/R_POMI_4: C38.2, J9.21 (R_POMI)
/L_MOPI: J2.18 (L_MOPI), J3.18 (L_MOPI), J4.18 (L_MOPI), J5.18 (L_MOPI), J7.18 (L_MOPI), J8.18 (L_MOPI), J9.18 (L_MOPI); also elsewhere on the board
/R_MOPI: J2.19 (R_MOPI), J3.19 (R_MOPI), J4.19 (R_MOPI), J5.19 (R_MOPI), J7.19 (R_MOPI), J8.19 (R_MOPI), J9.19 (R_MOPI); also elsewhere on the board
/~Mute_CH1: R10.2, R11.2, R12.2, R13.2; also elsewhere on the board
/~Mute_CH2: R20.2, R21.2, R22.2, R23.2; also elsewhere on the board
/~Mute_CH3: R30.2, R31.2, R32.2, R33.2; also elsewhere on the board
/~Mute_CH4: R40.2, R41.2, R42.2, R43.2; also elsewhere on the board
/~Mute_CH6: R64.2, R65.2, R66.2, R67.2; also elsewhere on the board
/~Mute_CH7: R74.2, R75.2, R76.2, R77.2; also elsewhere on the board
/~Mute_CH8: R84.2, R85.2, R86.2, R87.2; also elsewhere on the board
GND: C8.2, C9.2, C12.2, C13.2, C16.2, C17.2, C20.2, C21.2, C31.2, C32.2, C35.2, C36.2, C39.2, C40.2, J2.2 (GND), J2.4 (GND), J2.11 (GND), J2.13 (AGND), J2.15 (AGND), J2.17 (AGND), J2.20 (AGND), J2.22 (AGND), J2.24 (AGND), J2.29 (GND), J2.32 (GND), J2.33 (GND), J2.35 (GND), J3.2 (GND), J3.4 (GND), J3.11 (GND), J3.13 (AGND), J3.15 (AGND), J3.17 (AGND), J3.20 (AGND), J3.22 (AGND), J3.24 (AGND), J3.29 (GND), J3.32 (GND), J3.33 (GND), J3.35 (GND), J4.2 (GND), J4.4 (GND), J4.11 (GND), J4.13 (AGND), J4.15 (AGND), J4.17 (AGND), J4.20 (AGND), J4.22 (AGND), J4.24 (AGND), J4.29 (GND), J4.32 (GND), J4.33 (GND), J4.35 (GND), J5.2 (GND), J5.4 (GND), J5.11 (GND), J5.13 (AGND), J5.15 (AGND), J5.17 (AGND), J5.20 (AGND), J5.22 (AGND), J5.24 (AGND), J5.29 (GND), J5.32 (GND), J5.33 (GND), J5.35 (GND), J7.2 (GND), J7.4 (GND), J7.11 (GND), J7.13 (AGND), J7.15 (AGND), J7.17 (AGND), J7.20 (AGND), J7.22 (AGND), J7.24 (AGND), J7.29 (GND), J7.32 (GND), J7.33 (GND), J7.35 (GND), J8.2 (GND), J8.4 (GND), J8.11 (GND), J8.13 (AGND), J8.15 (AGND), J8.17 (AGND), J8.20 (AGND), J8.22 (AGND), J8.24 (AGND), J8.29 (GND), J8.32 (GND), J8.33 (GND), J8.35 (GND), J9.2 (GND), J9.4 (GND), J9.11 (GND), J9.13 (AGND), J9.15 (AGND), J9.17 (AGND), J9.20 (AGND), J9.22 (AGND), J9.24 (AGND), J9.29 (GND), J9.32 (GND), J9.33 (GND), J9.35 (GND), U6.3 (+), U6.5 (+), U7.2, U7.4, U8.2, U8.4, U9.3 (+), U9.5 (+), U10.2, U10.4, U11.2, U11.4, U12.3 (+), U12.5 (+), U13.2, U13.4, U14.2, U14.4, U15.3 (+), U15.5 (+), U16.2, U16.4, U17.2, U17.4, U24.3 (+), U24.5 (+), U25.2, U25.4, U26.2, U26.4, U27.3 (+), U27.5 (+), U28.2, U28.4, U29.2, U29.4, U30.3 (+), U30.5 (+), U31.2, U31.4, U32.2, U32.4; also elsewhere on the board
unnamed: C6.1, R8.2
unnamed: C7.1, R9.2
unnamed: C10.1, R18.2
unnamed: C11.1, R19.2
unnamed: C14.1, R28.2
unnamed: C15.1, R29.2
unnamed: C18.1, R38.2
unnamed: C19.1, R39.2
unnamed: C29.1, R62.2
unnamed: C30.1, R63.2
unnamed: C33.1, R72.2
unnamed: C34.1, R73.2
unnamed: C37.1, R82.2
unnamed: C38.1, R83.2
unnamed: R10.1, U7.1
unnamed: R11.1, U8.1
unnamed: R12.1, U7.3
unnamed: R13.1, U8.3
unnamed: R14.1, R16.2, U7.5
unnamed: R15.1, R17.2, U8.5
unnamed: R20.1, U10.1
unnamed: R21.1, U11.1
unnamed: R22.1, U10.3
unnamed: R23.1, U11.3
unnamed: R24.1, R26.2, U10.5
unnamed: R25.1, R27.2, U11.5
unnamed: R30.1, U13.1
unnamed: R31.1, U14.1
unnamed: R32.1, U13.3
unnamed: R33.1, U14.3
unnamed: R34.1, R36.2, U13.5
unnamed: R35.1, R37.2, U14.5
unnamed: R40.1, U16.1
unnamed: R41.1, U17.1
unnamed: R42.1, U16.3
unnamed: R43.1, U17.3
unnamed: R44.1, R46.2, U16.5
unnamed: R45.1, R47.2, U17.5
unnamed: R64.1, U25.1
unnamed: R65.1, U26.1
unnamed: R66.1, U25.3
unnamed: R67.1, U26.3
unnamed: R68.1, R70.2, U25.5
unnamed: R69.1, R71.2, U26.5
unnamed: R74.1, U28.1
unnamed: R75.1, U29.1
unnamed: R76.1, U28.3
unnamed: R77.1, U29.3
unnamed: R78.1, R80.2, U28.5
unnamed: R79.1, R81.2, U29.5
unnamed: R84.1, U31.1
unnamed: R85.1, U32.1
unnamed: R86.1, U31.3
unnamed: R87.1, U32.3
unnamed: R88.1, R90.2, U31.5
unnamed: R89.1, R91.2, U32.5
unnamed: U6.1, U7.6, U7.8
unnamed: U6.7, U8.6, U8.8
unnamed: R8.1, R14.2, U6.2 (-), U7.7
unnamed: R9.1, R15.2, U6.6 (-), U8.7
unnamed: R18.1, R24.2, U9.2 (-), U10.7
unnamed: R19.1, R25.2, U9.6 (-), U11.7
unnamed: U9.1, U10.6, U10.8
unnamed: U9.7, U11.6, U11.8
unnamed: U12.1, U13.6, U13.8
unnamed: U12.7, U14.6, U14.8
unnamed: R28.1, R34.2, U12.2 (-), U13.7
unnamed: R29.1, R35.2, U12.6 (-), U14.7
unnamed: U15.1, U16.6, U16.8
unnamed: U15.7, U17.6, U17.8
unnamed: R38.1, R44.2, U15.2 (-), U16.7
unnamed: R39.1, R45.2, U15.6 (-), U17.7
unnamed: U24.1, U25.6, U25.8
unnamed: U24.7, U26.6, U26.8
unnamed: R62.1, R68.2, U24.2 (-), U25.7
unnamed: R63.1, R69.2, U24.6 (-), U26.7
unnamed: U27.1, U28.6, U28.8
unnamed: U27.7, U29.6, U29.8
unnamed: R72.1, R78.2, U27.2 (-), U28.7
unnamed: R73.1, R79.2, U27.6 (-), U29.7
unnamed: U30.1, U31.6, U31.8
unnamed: U30.7, U32.6, U32.8
unnamed: R82.1, R88.2, U30.2 (-), U31.7
unnamed: R83.1, R89.2, U30.6 (-), U32.7

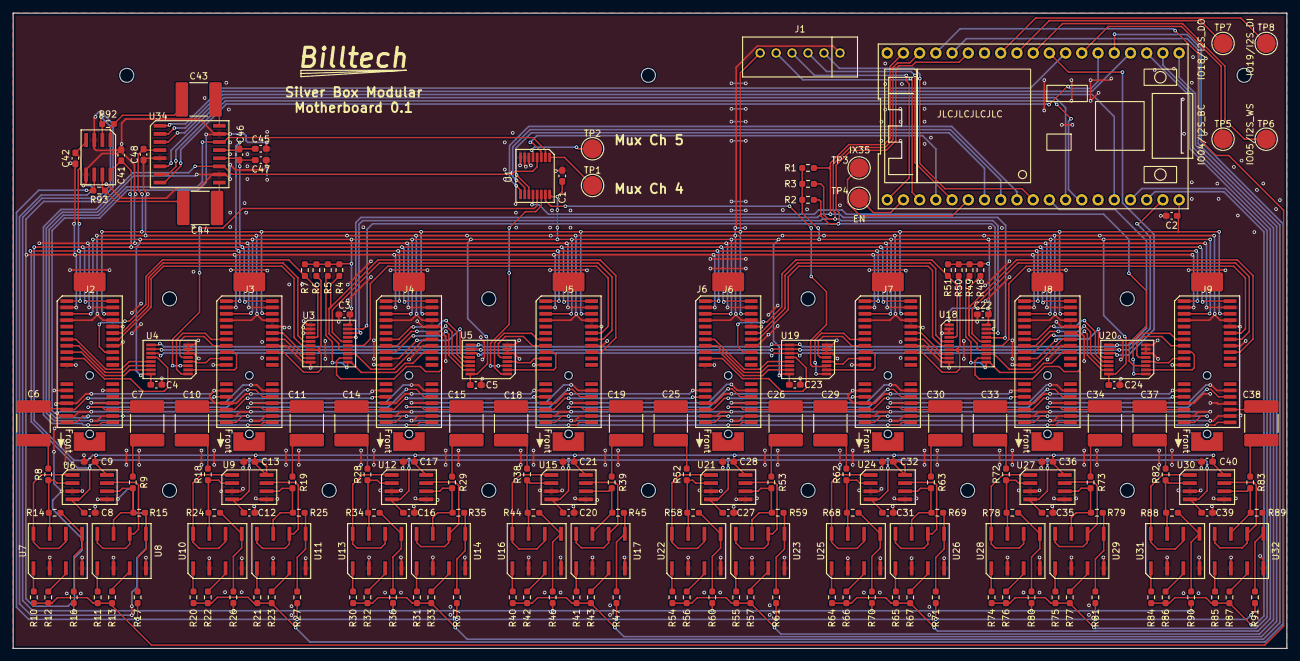
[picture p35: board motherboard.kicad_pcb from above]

Board: 2 copper layers, 199.5 x 99.5 mm, 192 parts (0 on the bottom side), 221 nets.

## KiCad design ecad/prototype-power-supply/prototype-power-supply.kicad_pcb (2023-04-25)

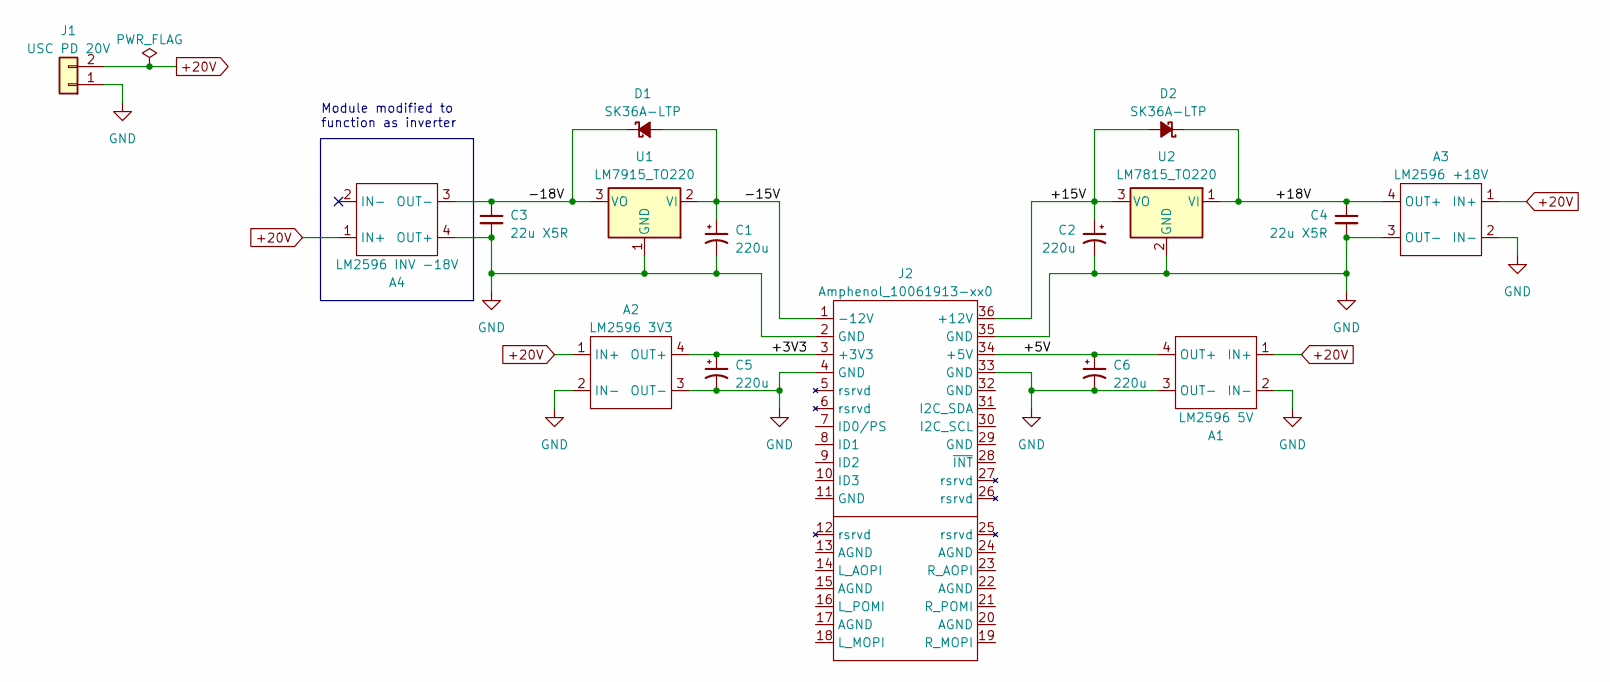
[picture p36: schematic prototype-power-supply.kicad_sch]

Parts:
A1: LM2596 5V; LM2596 module
A2: LM2596 3V3; LM2596 module
A3: LM2596 +18V; LM2596 module
A4: LM2596 INV -18V; LM2596 module
C1, C2, C5, C6: 220u; CP_Elec_12.5x13.5
C3, C4: 22u X5R; C_1210_3225Metric
D1, D2: SK36A-LTP; D_SMA_Handsoldering
J1: USC PD 20V; JST_XH_B2B-XH-A_1x02_P2.50mm_Vertical
J2: Amphenol_10061913-xx0; Card Edge board Amphenol 10061913-100PLF
U1: LM7915_TO220; TO-220-3_Vertical
U2: LM7815_TO220; TO-220-3_Vertical

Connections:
+20V: A1.1 (IN+), A2.1 (IN+), A3.1 (IN+), A4.1 (IN+), J1.2
/+3V3: A2.4 (OUT+), C5.1, J2.3 (+3V3)
/+5V: A1.4 (OUT+), C6.1, J2.34 (+5V)
/+15V: C2.1, D2.2 (A), J2.36 (+12V), U2.3 (VO)
/+18V: A3.4 (OUT+), C4.1, D2.1 (K), U2.1 (VI)
/-15V: C1.1, D1.2 (A), J2.1 (-12V), U1.2 (VI)
/-18V: A4.3 (OUT-), C3.1, D1.1 (K), U1.3 (VO)
GND: A1.2 (IN-), A1.3 (OUT-), A2.2 (IN-), A2.3 (OUT-), A3.2 (IN-), A3.3 (OUT-), A4.4 (OUT+), C1.2, C2.2, C3.2, C4.2, C5.2, C6.2, J1.1, J2.2 (GND), J2.4 (GND), J2.33 (GND), J2.35 (GND), U1.1 (GND), U2.2 (GND)

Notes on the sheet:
Module modified to function as inverter

Board: 2 copper layers, 16 parts (2 on the bottom side), 8 nets, no tracks yet.

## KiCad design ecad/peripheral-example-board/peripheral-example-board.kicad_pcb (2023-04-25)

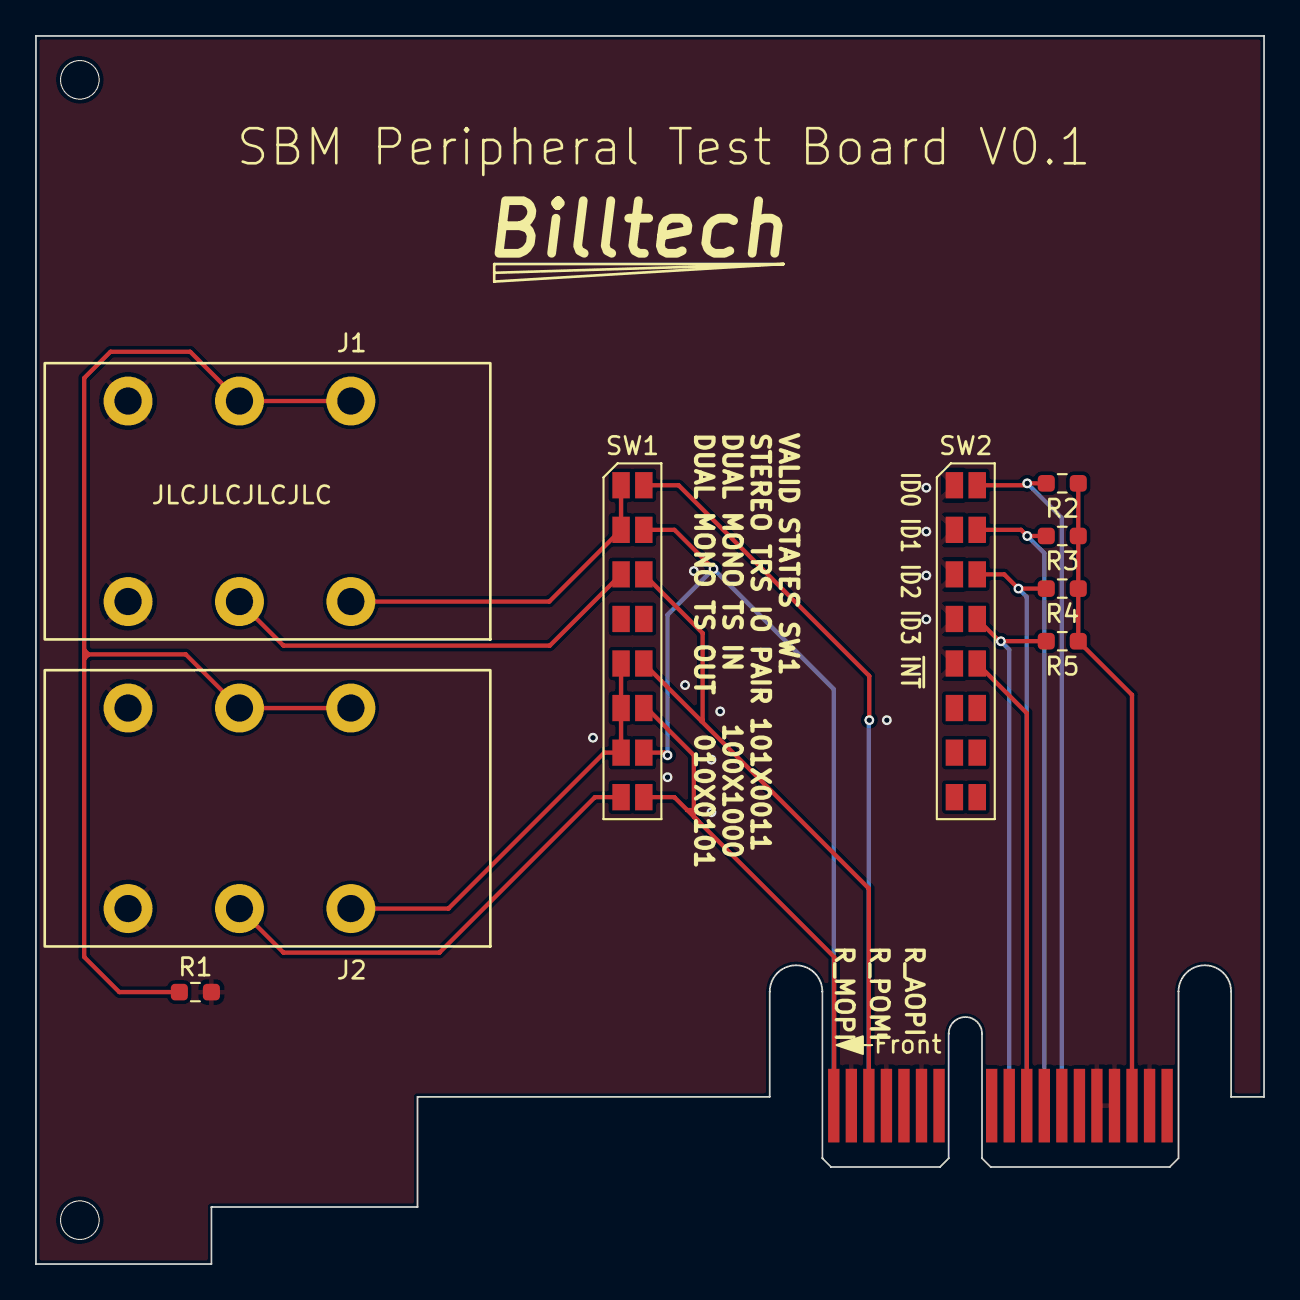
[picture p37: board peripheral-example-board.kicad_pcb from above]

Board: 2 copper layers, 70.0 x 70.0 mm, 11 parts (0 on the bottom side), 16 nets.

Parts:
J1, J2: Amphenol_ACJS-MHOM; ACJS-MHOM
LOGO: Billtech
P1: Amphenol_10061913-xx0; Card Edge board Amphenol 10061913-100PLF
R1, R2, R3, R4, R5: 10k; R_0603_1608Metric_Pad0.98x0.95mm_HandSolder
SW1, SW2: SW_DIP_x08; 1x8 solder bridge 1x1.5x0.3

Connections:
/+5V: P1.34 (+5V), R2.1, R3.1, R4.1, R5.1
/ID0: P1.7 (ID0/PS), R2.2, SW2.16
/ID1: P1.8 (ID1), R3.2, SW2.15
/ID2: P1.9 (ID2), R4.2, SW2.14
/ID3: P1.10 (ID3), R5.2, SW2.13
/L_MOPI: P1.18 (L_MOPI), SW1.10, SW1.15
/L_POMI: P1.16 (L_POMI), SW1.16
/R1: J1.R, SW1.3
/R2: J2.R, SW1.8
/R_MOPI: P1.19 (R_MOPI), SW1.9, SW1.11
/R_POMI: P1.21 (R_POMI), SW1.12, SW1.14
/T1: J1.T, SW1.1, SW1.2
/T2: J2.T, SW1.5, SW1.6, SW1.7
/~INT: P1.28 (~INT), SW2.12
GND: J1.S, J1.SN, J2.S, J2.SN, P1.2 (GND), P1.4 (GND), P1.11 (GND), P1.13 (AGND), P1.15 (AGND), P1.17 (AGND), P1.20 (AGND), P1.22 (AGND), P1.24 (AGND), P1.29 (GND), P1.32 (GND), P1.33 (GND), P1.35 (GND), R1.2, SW2.1, SW2.2, SW2.3, SW2.4, SW2.5
unnamed: J1.RN, J1.TN, J2.RN, J2.TN, R1.1

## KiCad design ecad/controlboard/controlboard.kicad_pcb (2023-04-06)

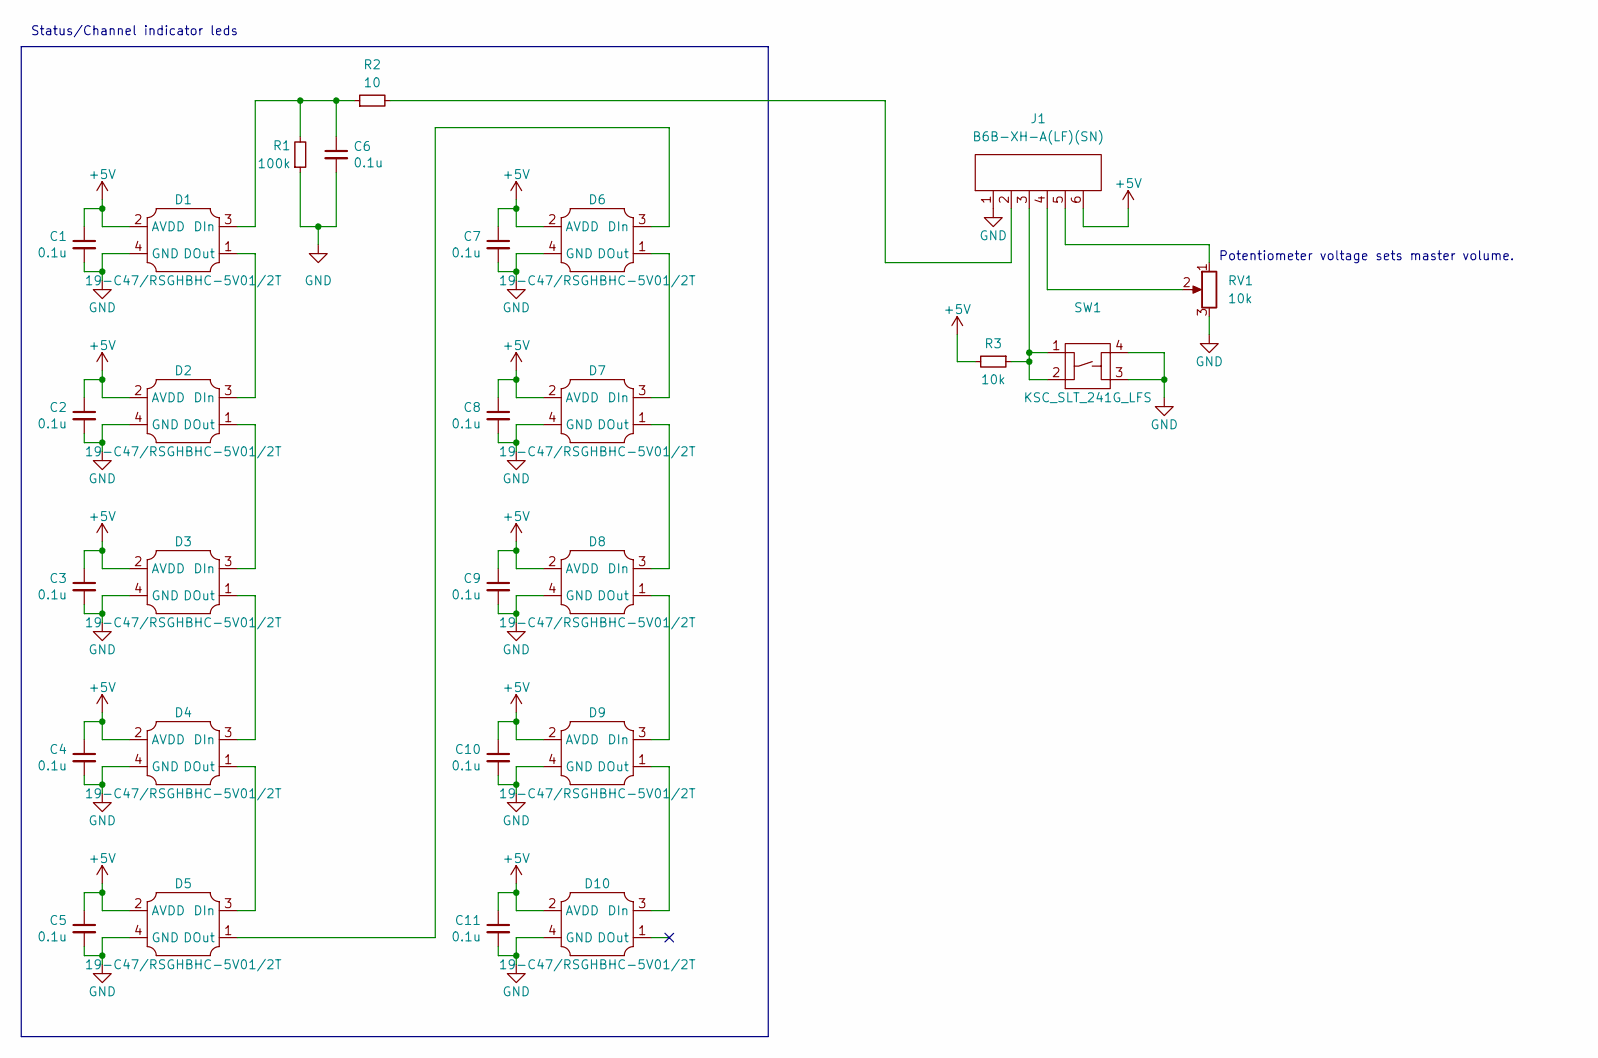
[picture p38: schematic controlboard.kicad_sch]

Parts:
C1, C2, C3, C4, C5, C6, C7, C8, C9, C10, C11: 0.1u; C_0603_1608Metric_Pad1.08x0.95mm_HandSolder
D1, D2, D3, D4, D5, D6, D7, D8, D9, D10: 19-C47/RSGHBHC-5V01/2T; 19-C47 RSGHBHC-5V01 2T
J1: B6B-XH-A(LF)(SN)
R1: 100k; R_0603_1608Metric_Pad0.98x0.95mm_HandSolder
R2: 10; R_0603_1608Metric_Pad0.98x0.95mm_HandSolder
R3: 10k; R_0603_1608Metric_Pad0.98x0.95mm_HandSolder
RV1: 10k; Bourns PTV11-4425A
SW1: KSC_SLT_241G_LFS; KSC SLT 241G LFS

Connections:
+5V: C1.1, C2.1, C3.1, C4.1, C5.1, C7.1, C8.1, C9.1, C10.1, C11.1, D1.2 (AVDD), D2.2 (AVDD), D3.2 (AVDD), D4.2 (AVDD), D5.2 (AVDD), D6.2 (AVDD), D7.2 (AVDD), D8.2 (AVDD), D9.2 (AVDD), D10.2 (AVDD), J1.6, R3.2
GND: C1.2, C2.2, C3.2, C4.2, C5.2, C6.2, C7.2, C8.2, C9.2, C10.2, C11.2, D1.4 (GND), D2.4 (GND), D3.4 (GND), D4.4 (GND), D5.4 (GND), D6.4 (GND), D7.4 (GND), D8.4 (GND), D9.4 (GND), D10.4 (GND), J1.1, R1.1, RV1.3, SW1.3, SW1.4
unnamed: C6.1, D1.3 (DIn), R1.2, R2.1
unnamed: D1.1 (DOut), D2.3 (DIn)
unnamed: D2.1 (DOut), D3.3 (DIn)
unnamed: D3.1 (DOut), D4.3 (DIn)
unnamed: D4.1 (DOut), D5.3 (DIn)
unnamed: D5.1 (DOut), D6.3 (DIn)
unnamed: D6.1 (DOut), D7.3 (DIn)
unnamed: D7.1 (DOut), D8.3 (DIn)
unnamed: D8.1 (DOut), D9.3 (DIn)
unnamed: D9.1 (DOut), D10.3 (DIn)
unnamed: J1.2, R2.2
unnamed: J1.3, R3.1, SW1.1, SW1.2
unnamed: J1.4, RV1.2
unnamed: J1.5, RV1.1

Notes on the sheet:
Status/Channel indicator leds
Potentiometer voltage sets master volume.

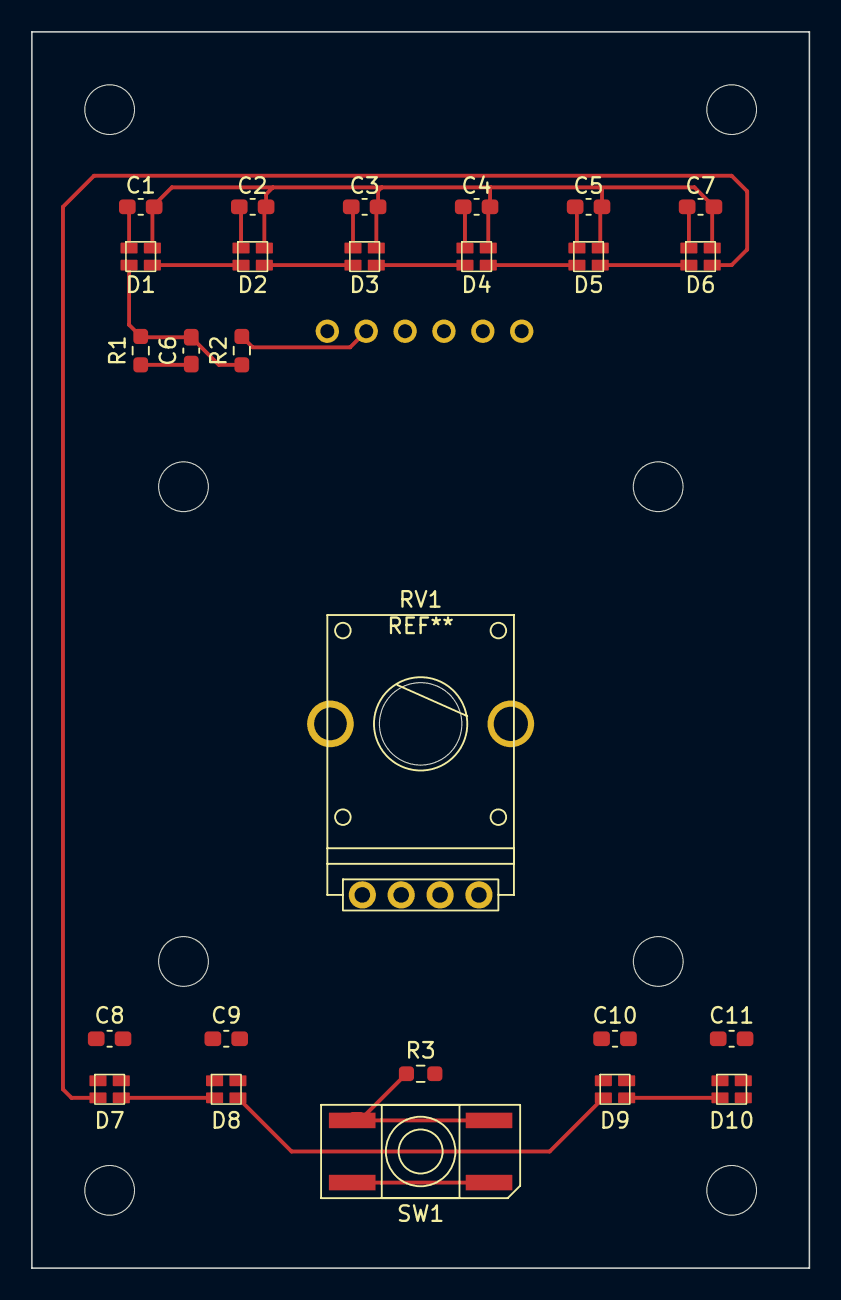
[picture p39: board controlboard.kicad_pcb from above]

Board: 2 copper layers, 50.0 x 79.5 mm, 27 parts (1 on the bottom side), 16 nets.

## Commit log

2023-02-01 Add 3d models for some IC parts
    [Bourns PTV111-4425A.step]
2023-02-01 Huge overhaul of whole project, nearly ready for PCB prototype layout.
    [3.sch, 3_5mmInModule.sch, 3_5mmModule.sch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]
2023-02-01 Remove kicad autobackups from git
2023-02-02 Update to Kicad 7 and generate PDF schematic.
    [BP_4Board_Control_and_Connect.kicad_sch, BP_Master_sum.kicad_sch, Channel.kicad_sch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]
2023-02-02 Add link to pdf schematic.
2023-02-03 More 3d Models and small fixes to footprints.
    [Amphenol 10061913-xx0.stp, NodeMCU ESP-32S.step]
2023-02-03 Fixes to footprint numbering in multi-unit parts.
    [BP_4Board_Control_and_Connect.kicad_sch, BP_Master_sum.kicad_sch, Channel.kicad_sch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]
2023-02-03 Begin rough PCB layout.
    [silver-box-modular.kicad_pcb]
2023-02-09 Small fixes/improvements to relay IC 3d models.
    [CPC2317N.step, TLP4026G.step]
2023-02-09 Layout signal conditioning portion with approximate traces, update status and next steps in readme.
    [silver-box-modular.kicad_pcb]
2023-03-16 Continue board layout, partial power and digital signals are laid.
    [silver-box-modular.kicad_pcb]
2023-03-17 2023.03.17 I2C out to master is current sticking point. Also needs review of grounds.
    [silver-box-modular.kicad_pcb]
2023-03-18 Route mutes and i2c master, rough positioning of esp32, will likely move towards a corner later.
    [silver-box-modular.kicad_pcb]
2023-03-27 Route all traces, needs review. Still needs silkscreen cleanup and conversion to true two board file.
    [silver-box-modular.kicad_pcb]
2023-03-28 Change mechanical pad to polyline to avoid drc complaint with through hole.
2023-03-28 Center footprint anchor point of switch
2023-03-28 Full layout for review after checking mechanical assembly.
    [silver-box-modular.kicad_pcb]
2023-03-28 Separate the board files and export .step so that the mechanical assembly can be reviewed.
    [silver-box-modular_control-panel.kicad_pcb, silver-box-modular_control-panel.step, silver-box-modular_main-board.kicad_pcb]
2023-03-28 Revise next steps as first round of pcb design wraps up.
2023-03-30 Split into truly multiboard preoject to simplify* organization (*Hopefully!)
    [BP_4Board_Control_and_Connect.kicad_sch, BP_Channel.kicad_sch, BP_Master_sum.kicad_sch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]
2023-03-30 Add new peripheral example board to better determine peripheral envelope and orientation in 3d space. Add several new parts to symbols, footprints, and 3dmodels
    [ACJS-MHOM.step, CK switches KSC SLT G.step, Neutrik ncj9fi-h-0.step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]
2023-03-31 Small changes and cleanup as 3dmodels are pieced together.
    [TLP4026G.step, controlboard.kicad_pcb, controlboard.step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]
2023-03-31 Fixes for manufacturer models that had geometry errors in onshape.
    [ACJS-MHOM.step, peripheral-example-board.kicad_pcb, pjras2x1s_series.step]
2023-03-31 Change addressable LED to new part that is still available.
    [19-C47 RSGHBHC-5V01 2T.step, controlboard.kicad_pcb, controlboard.kicad_sch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]
2023-04-02 Good state for mechanical assembly, can bounce back to pcb review now that board outlines are close.
    [JST-XH-6A.step, controlboard.kicad_pcb, controlboard.step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]
2023-04-06 Fix 3d models getting duplicated output in .step export
    [BP_4Board_Control_and_Connect.kicad_sch, BP_Channel.kicad_sch, BP_Master_sum.kicad_sch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]
2023-04-10 Small tweaks to routing for better signal return paths. Fix minor footprint issues: missing courtyards, smt parts labeled as through hole.
    [motherboard.kicad_pcb]
2023-04-11 Add billtech logo footprint.
2023-04-11 Add silkscreen markings.
    [motherboard.kicad_pcb]
2023-04-25 Updates and additions for peripheral test board and power supply prototype
    [motherboard.kicad_pcb]
2023-04-25 Add manufacturer part numbers into Kicad Schematics
    [BP_4Board_Control_and_Connect.kicad_sch, BP_Channel.kicad_sch, BP_Master_sum.kicad_sch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]
2023-04-25 Version 0.1 of the peripheral example board sent to PCB manufaturer.
    [peripheral-example-board.kicad_pcb, peripheral-example-board.kicad_sch]
2023-04-25 Add 3d model of bulk power cap.
    [Cap_Elec_12.5x13.5.step]
2023-04-25 Add symbols for prototype power board
2023-04-25 Begin design of protype power supply.
    [prototype-power-supply.kicad_pcb, prototype-power-supply.kicad_sch]
2023-04-25 Update schematic pdf and PCBA .step files
    [motherboard.kicad_pcb, peripheral-example-board.kicad_pcb, prototype-power-supply.kicad_pcb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]
2023-04-25 update current status and organization of project.
2023-04-27 Fix missing mask and paste layers on support pad of PCI connector. Open mask expansion slightly and close paste slightly.
    [motherboard.kicad_pcb]
2023-05-01 Update Net labels for better consistency.
    [motherboard.kicad_sch]
2023-05-01 Begin unit tests and driver for PGA231X volume control.
2023-05-01 Hardware target initial file for build chain test.
